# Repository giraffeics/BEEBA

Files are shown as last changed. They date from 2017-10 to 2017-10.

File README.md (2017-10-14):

# BEEBA

An 8-bit computer built using 7400 Series discrete logic chips.

## Repository Layout

The "CAD" folder contains all design files for the printed circuit boards. These are KiCAD documents.
The "Assembler" folder contains the C++ source code for the assembler, as well as the list of register names and some programs written in BEEBA assembly language. The assembler can be compiled with MinGW on Windows, and has not been tested on other compilers or operating systems.

## Assembly Language

Assembly language programs can be in any plain-text file format. The language is not case-sensitive. Each instruction copies eight bits of data from one register location to another. A line of code can follow one of three formats:

### COPY [read location] TO [write location]

Reads one byte of data from the register specified by [read location], writes data to the register specified by [write location].

### SET [write location] TO [data]

Writes a byte of data specified by [data] to the register specified by [write location]. [data] can be a two-digit hexadecimal number or a marker.

### MARK [marker name]

Marks the instruction position that corresponds to the following line of code. This does not represent an actual instruction. [marker name] can be referenced by SET instructions before or after the location of the marker, using a colon to specify which byte of the marker's location to use. This ranges from 0 (least significant) to 2 (most significant).

For all of these, any text after the last parameter will be ignored. However, it must be separated by a space or tab from the last parameter.

Register names are listed in REGISTER_NAMES.txt. The assembler uses this file to convert names to addresses while compiling programs.

## Using The Assembler

To use the assembler, simply drag assembly source files onto the compiled executable.

As BEEBA uses two physical ROM chips to store 16-bit-wide instructions, the assembler will output two .bin files. One of these is loaded onto the ROM chip on the left, the other is loaded onto the ROM chip on the right. They are named accordingly.

## Known Issues

When writing a constant to a register, the value will be corrupted unless the same data is sent to another register in the next instruction. The current workaround is to send data to NULL, which is an unused register.

The NES controller interface board cannot read the state of the A button. Pannenkoek2012 would love this.

The "Basic IO Board"'s input does not work at all. This was caused by oversights during the transition from TTL to CMOS. Output is still fully functional.

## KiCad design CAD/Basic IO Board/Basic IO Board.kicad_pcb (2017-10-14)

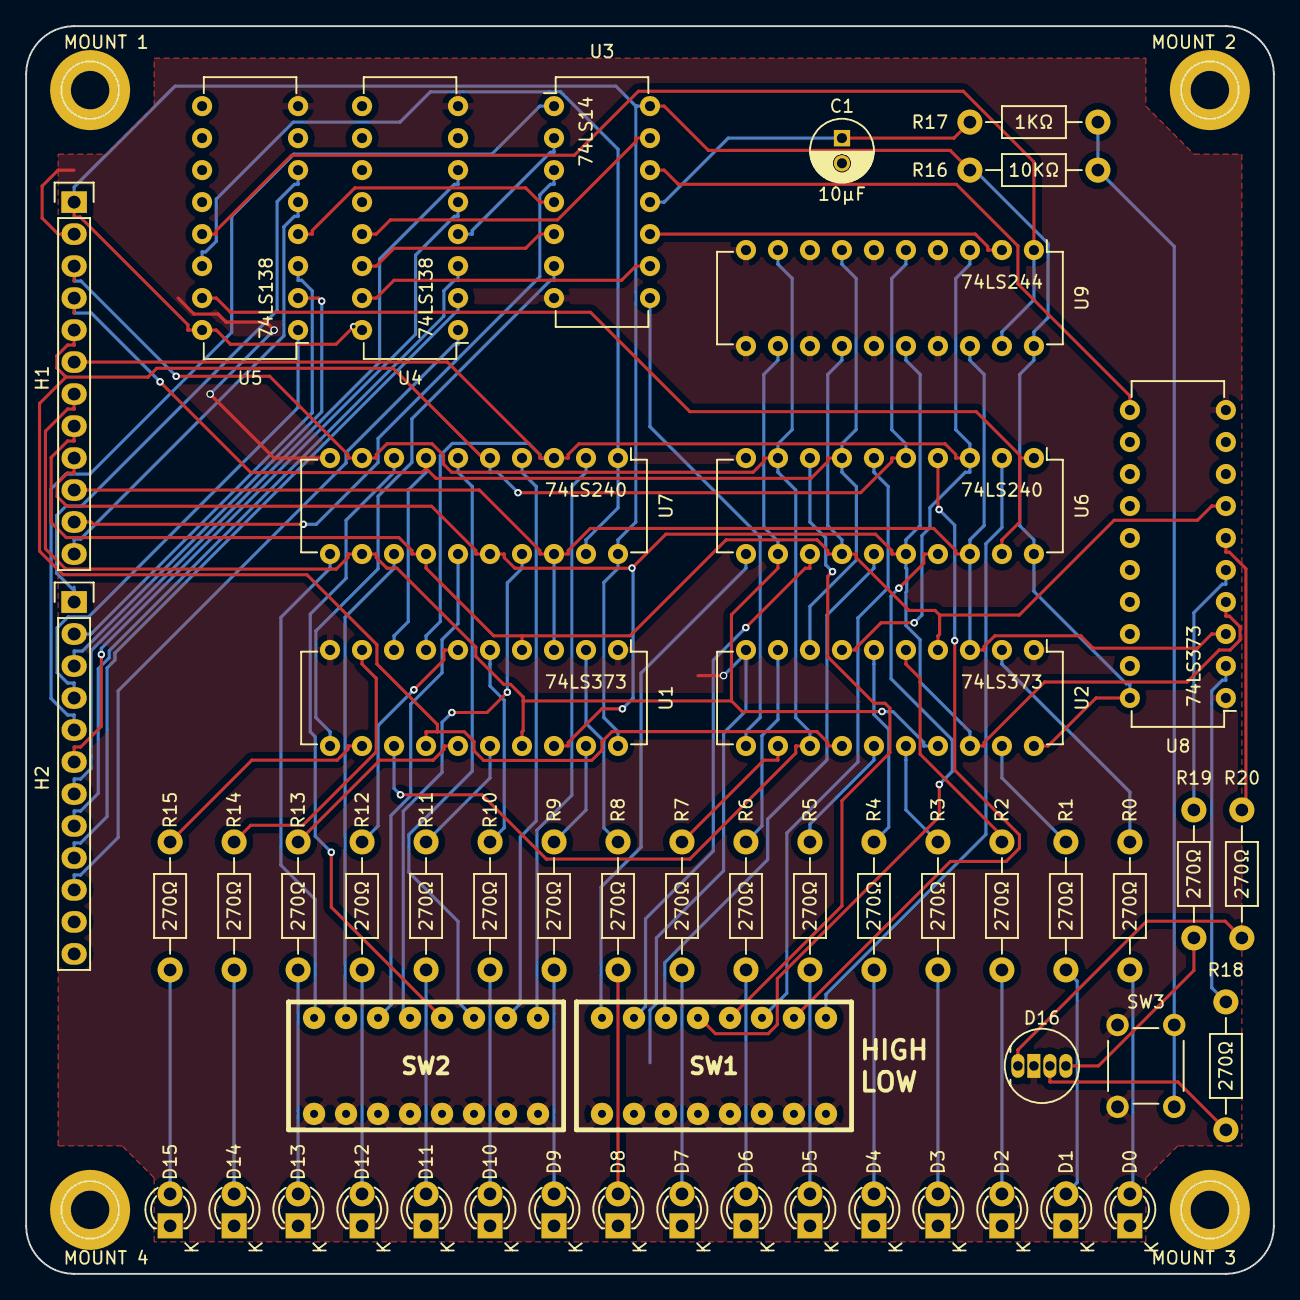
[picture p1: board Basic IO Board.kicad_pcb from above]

Board: 2 copper layers, 99.1 x 99.1 mm, 57 parts (0 on the bottom side), 90 nets.

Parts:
C1: 10µF; C_Radial_D5_L11_P2
D0, D1, D2, D3, D4, D5, D6, D7, D8, D9, D10, D11, D12, D13, D14, D15: Led_Small; LED-3MM
D16: LED_RCBG; LED-RGB-5MM_Common_Cathode
H1, H2: CONN_01X12; Socket_Strip_Straight_1x12
MOUNT 1, MOUNT 2, MOUNT 3, MOUNT 4: 1pin
R0, R1, R2, R3, R4, R5, R6, R7, R8, R9, R10, R11, R12, R13, R14, R15, R18, R19, R20: 270Ω; Resistor_Horizontal_RM10mm
R16: 10KΩ; Resistor_Horizontal_RM10mm
R17: 1KΩ; Resistor_Horizontal_RM10mm
SW1, SW2: DIPS_08; DIPS-DS08
SW3: SW_PUSH; switch_tactile_6mm
U1, U2, U8: 74LS373; DIP-20_W7.62mm
U3: 74LS14; DIP-14_W7.62mm
U4, U5: 74LS138; DIP-16_W7.62mm
U6, U7: 74LS240; DIP-20_W7.62mm
U9: 74LS244; DIP-20_W7.62mm

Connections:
DATA0: H1.10, U1.3, U2.3, U6.18, U7.18, U8.3, U9.18
DATA1: H1.9, U1.18, U2.18, U6.16, U7.16, U8.4, U9.16
DATA2: H1.8, U1.4, U2.4, U6.14, U7.14, U8.7, U9.14
DATA3: H1.7, U1.17, U2.17, U6.12, U7.12, U9.12
DATA4: H1.6, U1.7, U2.7, U6.3, U7.3, U9.3
DATA5: H1.5, U1.14, U2.14, U6.5, U7.5, U9.5
DATA6: H1.4, U1.8, U2.8, U6.7, U7.7, U9.7
DATA7: H1.3, U1.13, U2.13, U6.9, U7.9, U9.9
GND: C1.2, D0.1, D1.1, D2.1, D3.1, D4.1, D5.1, D6.1, D7.1, D8.1, D9.1, D10.1, D11.1, D12.1, D13.1, D14.1, D15.1, D16.2, H1.2, SW1.9, SW1.10, SW1.11, SW1.12, SW1.13, SW1.14, SW1.15, SW1.16, SW2.9, SW2.10, SW2.11, SW2.12, SW2.13, SW2.14, SW2.15, SW2.16, SW3.1, U1.1, U1.10, U2.1, U2.10, U3.7, U4.8, U5.8, U6.10, U7.10, U8.1, U8.10, U9.4, U9.6, U9.8, U9.10, U9.11, U9.13, U9.15, U9.17
unnamed: C1.1, R17.1, U3.11
unnamed: D0.2, R0.2
unnamed: D1.2, R1.2
unnamed: D2.2, R2.2
unnamed: D3.2, R3.2
unnamed: D4.2, R4.2
unnamed: D5.2, R5.2
unnamed: D6.2, R6.2
unnamed: D7.2, R7.2
unnamed: D8.2, R8.2
unnamed: D9.2, R9.2
unnamed: D10.2, R10.2
unnamed: D11.2, R11.2
unnamed: D12.2, R12.2
unnamed: D13.2, R13.2
unnamed: D14.2, R14.2
unnamed: D15.2, R15.2
unnamed: D16.1, R20.1
unnamed: D16.3, R18.1
unnamed: D16.4, R19.1
unnamed: R0.1, U2.2
unnamed: R1.1, U2.19
unnamed: R2.1, U2.5
unnamed: R3.1, U2.16
unnamed: R4.1, U2.6
unnamed: R5.1, U2.15
unnamed: R6.1, U2.9
unnamed: R7.1, U2.12
unnamed: R8.1, U1.2
unnamed: R9.1, U1.19
unnamed: R10.1, U1.5
unnamed: R11.1, U1.16
unnamed: R12.1, U1.6
unnamed: R13.1, U1.15
unnamed: R14.1, U1.9
unnamed: R15.1, U1.12
unnamed: R16.2, R17.2, SW3.2
unnamed: R18.2, U8.2
unnamed: R19.2, U8.5
unnamed: R20.2, U8.6
unnamed: SW1.1, U6.2
unnamed: SW1.2, U6.4
unnamed: SW1.3, U6.6
unnamed: SW1.4, U6.8
unnamed: SW1.5, U6.17
unnamed: SW1.6, U6.15
unnamed: SW1.7, U6.13
unnamed: SW1.8, U6.11
unnamed: SW2.1, U7.2
unnamed: SW2.2, U7.4
unnamed: SW2.3, U7.6
unnamed: SW2.4, U7.8
unnamed: SW2.5, U7.17
unnamed: SW2.6, U7.15
unnamed: SW2.7, U7.13
unnamed: SW2.8, U7.11
unnamed: U1.11, U3.6
unnamed: U2.11, U3.8
unnamed: U3.2, U4.4
unnamed: U3.4, U5.4
unnamed: U3.10, U9.2
unnamed: U3.12, U8.11
READ0: H2.4, U5.1
READ1: H2.3, U5.2
READ2: H2.2, U5.3
READ3: H2.1, U5.6
READ4: H1.12, U5.5
READ5: H1.11, U3.3
RS40: U5.15, U6.1, U6.19
RS41: U5.14, U7.1, U7.19
RS42: U5.13, U9.1, U9.19
VCC: H1.1, R16.1, U1.20, U2.20, U3.14, U4.16, U5.16, U6.20, U7.20, U8.20, U9.20
WRITE0: H2.10, U4.1
WRITE1: H2.9, U4.2
WRITE2: H2.8, U4.3
WRITE3: H2.7, U4.6
WRITE4: H2.6, U4.5
WRITE5: H2.5, U3.1
WS40: U3.9, U4.15
WS41: U3.5, U4.14
WS42: U3.13, U4.13

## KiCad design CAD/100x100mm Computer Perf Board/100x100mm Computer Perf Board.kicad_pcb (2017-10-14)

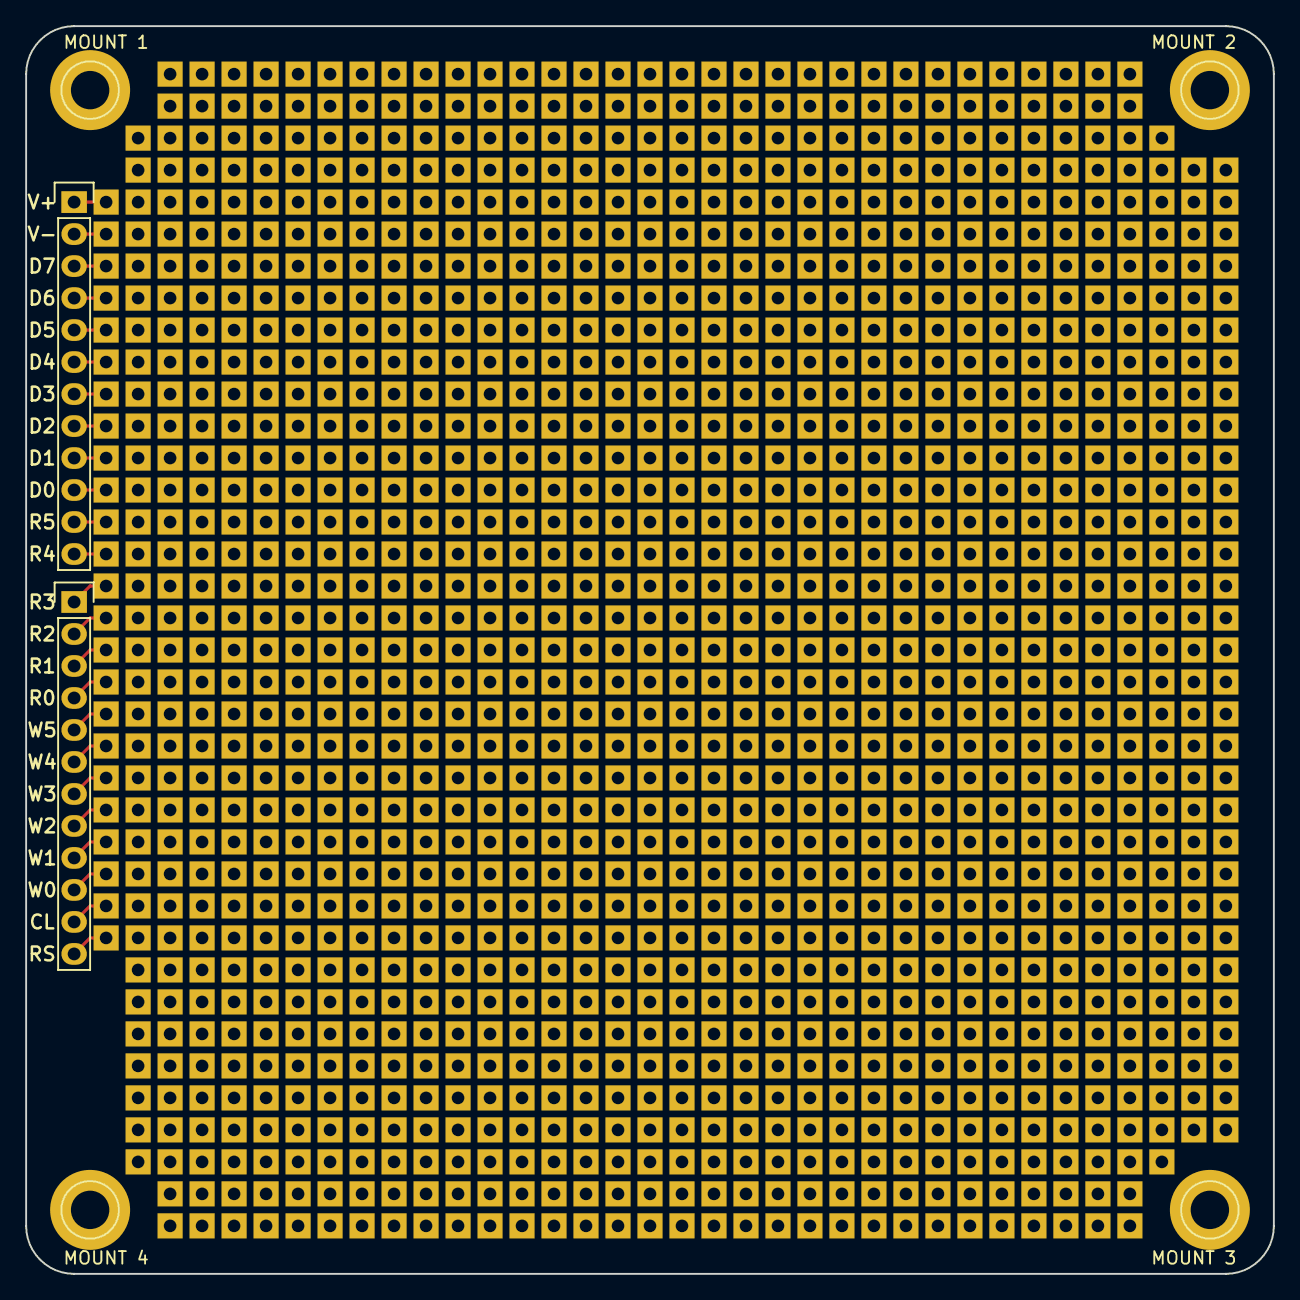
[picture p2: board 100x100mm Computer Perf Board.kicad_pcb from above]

Board: 2 copper layers, 99.1 x 99.1 mm, 1283 parts (0 on the bottom side), 24 nets.

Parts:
111, 112, 113, 114, 115, 116, 117, 118, 119, 121, 122, 123, 124, 125, 126, 127, 128, 129, 131, 132, 133, 134, 135, 136, 137, 138, 139, 141, 142, 143, 144, 145, 146, 147, 148, 149, 151, 152, 153, 154, 155, 156, 157, 158, 159, 161, 162, 163, 164, 165, 166, 167, 168, 169, 171, 172, 173, 174, 175, 176, 177, 178, 179, 181, 182, 183, 184, 185, 186, 187, 188, 189, 191, 192, 193, 194, 195, 196, 197, 198, 199, 1101, 1102, 1103, 1104, 1105, 1106, 1107, 1108, 1109, 1110, 1111, 1111#2, 1111#3, 1112, 1112#2, 1112#3, 1113, 1113#2, 1113#3, 1114, 1114#2, 1114#3, 1115, 1115#2, 1115#3, 1116, 1116#2, 1116#3, 1117, 1117#2, 1117#3, 1118, 1118#2, 1118#3, 1119, 1119#2, 1119#3, 1120, 1121, 1121#2, 1122, 1122#2, 1123, 1123#2, 1124, 1124#2, 1125, 1125#2, 1126, 1126#2, 1127, 1127#2, 1128, 1128#2, 1129, 1129#2, 1130, 1131, 1131#2, 1132, 1132#2, 1133, 1133#2, 1134, 1134#2, 1135, 1135#2, 1136, 1136#2, 1137, 1137#2, 1138, 1139, 1141, 1142, 1143, 1144, 1145, 1146, 1147, 1148, 1149, 1151, 1152, 1153, 1154, 1155, 1156, 1157, 1158, 1159, 1161, 1162, 1163, 1164, 1165, 1166, 1167, 1168, 1169, 1171, 1172, 1173, 1174, 1175, 1176, 1177, 1178, 1179, 1181, 1182, 1183, 1184, 1185, 1186, 1187, 1188, 1189, 1191, 1192, 1193, 1194, 1195, 1196, 1197, 1198, 1199, 1201, 1202, 1203, 1204, 1205, 1206, 1207, 1208, 1209, 1210, 1211, 1211#2, 1212, 1212#2, 1213, 1213#2, 1214, 1214#2, 1215, 1215#2, 1216, 1216#2, 1217, 1217#2, 1218, 1218#2, 1219, 1219#2, 1220, 1221, 1221#2, 1222, 1222#2, 1223, 1223#2, 1224, 1224#2, 1225, 1225#2, 1226, 1226#2, 1227, 1227#2, 1228, 1228#2, 1229, 1229#2, 1230, 1231, 1231#2, 1232, 1232#2, 1233, 1233#2, 1234, 1234#2, 1235, 1235#2, 1236, 1236#2, 1237, 1237#2, 1238, 1239, 1241, 1242, 1243, 1244, 1245, 1246, 1247, 1248, 1249, 1251, 1252, 1253, 1254, 1255, 1256, 1257, 1258, 1259, 1261, 1262, 1263, 1264, 1265, 1266, 1267, 1268, 1269, 1271, 1272, 1273, 1274, 1275, 1276, 1277, 1278, 1279, 1281, 1282, 1283, 1284, 1285, 1286, 1287, 1288, 1289, 1291, 1292, 1293, 1294, 1295, 1296, 1297, 1298, 1299, 1301, 1302, 1303, 1304, 1305, 1306, 1307, 1308, 1309, 1310, 1311, 1311#2, 1312, 1312#2, 1313, 1313#2, 1314, 1314#2, 1315, 1315#2, 1316, 1316#2, 1317, 1317#2, 1318, 1318#2, 1319, 1319#2, 1320, 1321, 1322, 1323, 1324, 1325, 1326, 1327, 1328, 1329, 1330, 1331, 1332, 1333, 1334, 1335, 1336, 1337, 1410, 1411, 1412, 1413, 1414, 1415, 1416, 1417, 1418, 1419, 1420, 1421, 1422, 1423, 1424, 1425, 1426, 1427, 1428, 1429, 1430, 1431, 1432, 1433, 1434, 1435, 1436, 1437, 1510, 1511, 1512, 1513, 1514, 1515, 1516, 1517, 1518, 1519, 1520, 1521, 1522, 1523, 1524, 1525, 1526, 1527, 1528, 1529, 1530, 1531, 1532, 1533, 1534, 1535, 1536, 1537, 1610, 1611, 1612, 1613, 1614, 1615, 1616, 1617, 1618, 1619, 1620, 1621, 1622, 1623, 1624, 1625, 1626, 1627, 1628, 1629, 1630, 1631, 1632, 1633, 1634, 1635, 1636, 1637, 1710, 1711, 1712, 1713, 1714, 1715, 1716, 1717, 1718, 1719, 1720, 1721, 1722, 1723, 1724, 1725, 1726, 1727, 1728, 1729, 1730, 1731, 1732, 1733, 1734, 1735, 1736, 1737, 1810, 1811, 1812, 1813, 1814, 1815, 1816, 1817, 1818, 1819, 1820, 1821, 1822, 1823, 1824, 1825, 1826, 1827, 1828, 1829, 1830, 1831, 1832, 1833, 1834, 1835, 1836, 1837, 1910, 1911, 1912, 1913, 1914, 1915, 1916, 1917, 1918, 1919, 1920, 1921, 1922, 1923, 1924, 1925, 1926, 1927, 1928, 1929, 1930, 1931, 1932, 1933, 1934, 1935, 1936, 1937, 11010, 11011, 11012, 11013, 11014, 11015, 11016, 11017, 11018, 11019, 11020, 11021, 11022, 11023, 11024, 11025, 11026, 11027, 11028, 11029, 11030, 11031, 11032, 11033, 11034, 11035, 11036, 11037, 11110, 11110#2, 11111, 11111#2, 11112, 11112#2, 11113, 11113#2, 11114, 11114#2, 11115, 11115#2, 11116, 11116#2, 11117, 11117#2, 11118, 11118#2, 11119, 11119#2, 11120, 11120#2, 11121, 11121#2, 11122, 11122#2, 11123, 11123#2, 11124, 11124#2, 11125, 11125#2, 11126, 11126#2, 11127, 11127#2, 11128, 11128#2, 11129, 11129#2, 11130, 11130#2, 11131, 11131#2, 11132, 11132#2, 11133, 11133#2, 11134, 11135, 11136, 11137, 11210, 11211, 11212, 11213, 11214, 11215, 11216, 11217, 11218, 11219, 11220, 11221, 11222, 11223, 11224, 11225, 11226, 11227, 11228, 11229, 11230, 11231, 11232, 11233, 11234, 11235, 11236, 11237, 11310, 11311, 11312, 11313, 11314, 11315, 11316, 11317, 11318, 11319, 11320, 11321, 11322, 11323, 11324, 11325, 11326, 11327, 11328, 11329, 11330, 11331, 11332, 11333, 11334, 11335, 11336, 11337, 11410, 11411, 11412, 11413, 11414, 11415, 11416, 11417, 11418, 11419, 11420, 11421, 11422, 11423, 11424, 11425, 11426, 11427, 11428, 11429, 11430, 11431, 11432, 11433, 11434, 11435, 11436, 11437, 11510, 11511, 11512, 11513, 11514, 11515, 11516, 11517, 11518, 11519, 11520, 11521, 11522, 11523, 11524, 11525, 11526, 11527, 11528, 11529, 11530, 11531, 11532, 11533, 11534, 11535, 11536, 11537, 11610, 11611, 11612, 11613, 11614, 11615, 11616, 11617, 11618, 11619, 11620, 11621, 11622, 11623, 11624, 11625, 11626, 11627, 11628, 11629, 11630, 11631, 11632, 11633, 11634, 11635, 11636, 11637, 11710, 11711, 11712, 11713, 11714, 11715, 11716, 11717, 11718, 11719, 11720, 11721, 11722, 11723, 11724, 11725, 11726, 11727, 11728, 11729, 11730, 11731, 11732, 11733, 11734, 11735, 11736, 11737, 11810, 11811, 11812, 11813, 11814, 11815, 11816, 11817, 11818, 11819, 11820, 11821, 11822, 11823, 11824, 11825, 11826, 11827, 11828, 11829, 11830, 11831, 11832, 11833, 11834, 11835, 11836, 11837, 11910, 11911, 11912, 11913, 11914, 11915, 11916, 11917, 11918, 11919, 11920, 11921, 11922, 11923, 11924, 11925, 11926, 11927, 11928, 11929, 11930, 11931, 11932, 11933, 11934, 11935, 11936, 11937, 12010, 12011, 12012, 12013, 12014, 12015, 12016, 12017, 12018, 12019, 12020, 12021, 12022, 12023, 12024, 12025, 12026, 12027, 12028, 12029, 12030, 12031, 12032, 12033, 12034, 12035, 12036, 12037, 12110, 12111, 12112, 12113, 12114, 12115, 12116, 12117, 12118, 12119, 12120, 12121, 12122, 12123, 12124, 12125, 12126, 12127, 12128, 12129, 12130, 12131, 12132, 12133, 12134, 12135, 12136, 12137, 12210, 12211, 12212, 12213, 12214, 12215, 12216, 12217, 12218, 12219, 12220, 12221, 12222, 12223, 12224, 12225, 12226, 12227, 12228, 12229, 12230, 12231, 12232, 12233, 12234, 12235, 12236, 12237, 12310, 12311, 12312, 12313, 12314, 12315, 12316, 12317, 12318, 12319, 12320, 12321, 12322, 12323, 12324, 12325, 12326, 12327, 12328, 12329, 12330, 12331, 12332, 12333, 12334, 12335, 12336, 12337, 12410, 12411, 12412, 12413, 12414, 12415, 12416, 12417, 12418, 12419, 12420, 12421, 12422, 12423, 12424, 12425, 12426, 12427, 12428, 12429, 12430, 12431, 12432, 12433, 12434, 12435, 12436, 12437, 12510, 12511, 12512, 12513, 12514, 12515, 12516, 12517, 12518, 12519, 12520, 12521, 12522, 12523, 12524, 12525, 12526, 12527, 12528, 12529, 12530, 12531, 12532, 12533, 12534, 12535, 12536, 12537, 12610, 12611, 12612, 12613, 12614, 12615, 12616, 12617, 12618, 12619, 12620, 12621, 12622, 12623, 12624, 12625, 12626, 12627, 12628, 12629, 12630, 12631, 12632, 12633, 12634, 12635, 12636, 12637, 12710, 12711, 12712, 12713, 12714, 12715, 12716, 12717, 12718, 12719, 12720, 12721, 12722, 12723, 12724, 12725, 12726, 12727, 12728, 12729, 12730, 12731, 12732, 12733, 12734, 12735, 12736, 12737, 12810, 12811, 12812, 12813, 12814, 12815, 12816, 12817, 12818, 12819, 12820, 12821, 12822, 12823, 12824, 12825, 12826, 12827, 12828, 12829, 12830, 12831, 12832, 12833, 12834, 12835, 12836, 12837, 12910, 12911, 12912, 12913, 12914, 12915, 12916, 12917, 12918, 12919, 12920, 12921, 12922, 12923, 12924, 12925, 12926, 12927, 12928, 12929, 12930, 12931, 12932, 12933, 12934, 12935, 12936, 12937, 13010, 13011, 13012, 13013, 13014, 13015, 13016, 13017, 13018, 13019, 13020, 13021, 13022, 13023, 13024, 13025, 13026, 13027, 13028, 13029, 13030, 13031, 13032, 13033, 13034, 13035, 13036, 13037, 13110, 13111, 13111#2, 13112, 13112#2, 13113, 13113#2, 13114, 13114#2, 13115, 13115#2, 13116, 13116#2, 13117, 13117#2, 13118, 13118#2, 13119, 13119#2, 13120, 13121, 13122, 13123, 13124, 13125, 13126, 13127, 13128, 13129, 13130, 13131, 13132, 13133, 13134, 13135, 13136, 13137, 131110, 131111, 131111#2, 131112, 131112#2, 131113, 131113#2, 131114, 131114#2, 131115, 131115#2, 131116, 131116#2, 131117, 131117#2, 131118, 131118#2, 131119, 131119#2, 131120, 131121, 131121#2, 131122, 131122#2, 131123, 131123#2, 131124, 131124#2, 131125, 131125#2, 131126, 131126#2, 131127, 131127#2, 131128, 131128#2, 131129, 131129#2, 131130, 131131, 131132, 131133, 1311110, 1311111, 1311112, 1311113, 1311114, 1311115, 1311116, 1311117, 1311118, 1311119, 1311120, 1311121, 1311122, 1311123, 1311124, 1311125, 1311126, 1311127, 1311128, 1311129, 1311130, 1311131, 1311210, 1311211, 1311212, 1311213, 1311214, 1311215, 1311216, 1311217, 1311218, 1311219, 1311220, 1311221, 1311222, 1311223, 1311224, 1311225, 1311226, 1311227, 1311228, 1311229, 1311230, 1311231: 1pin
H1, H2: CONN_01X12; Socket_Strip_Straight_1x12
H3, H4: CONN_01X12; 12pin_square_nodecor
MOUNT 1, MOUNT 2, MOUNT 3, MOUNT 4: 1pin

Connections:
DATA0: H1.10, H3.10
DATA1: H1.9, H3.9
DATA2: H1.8, H3.8
DATA3: H1.7, H3.7
DATA4: H1.6, H3.6
DATA5: H1.5, H3.5
DATA6: H1.4, H3.4
DATA7: H1.3, H3.3
GND: H1.2, H3.2
unnamed: H2.11, H4.11
unnamed: H2.12, H4.12
READ0: H2.4, H4.4
READ1: H2.3, H4.3
READ2: H2.2, H4.2
READ3: H2.1, H4.1
READ4: H1.12, H3.12
READ5: H1.11, H3.11
VCC: H1.1, H3.1
WRITE0: H2.10, H4.10
WRITE1: H2.9, H4.9
WRITE2: H2.8, H4.8
WRITE3: H2.7, H4.7
WRITE4: H2.6, H4.6
WRITE5: H2.5, H4.5

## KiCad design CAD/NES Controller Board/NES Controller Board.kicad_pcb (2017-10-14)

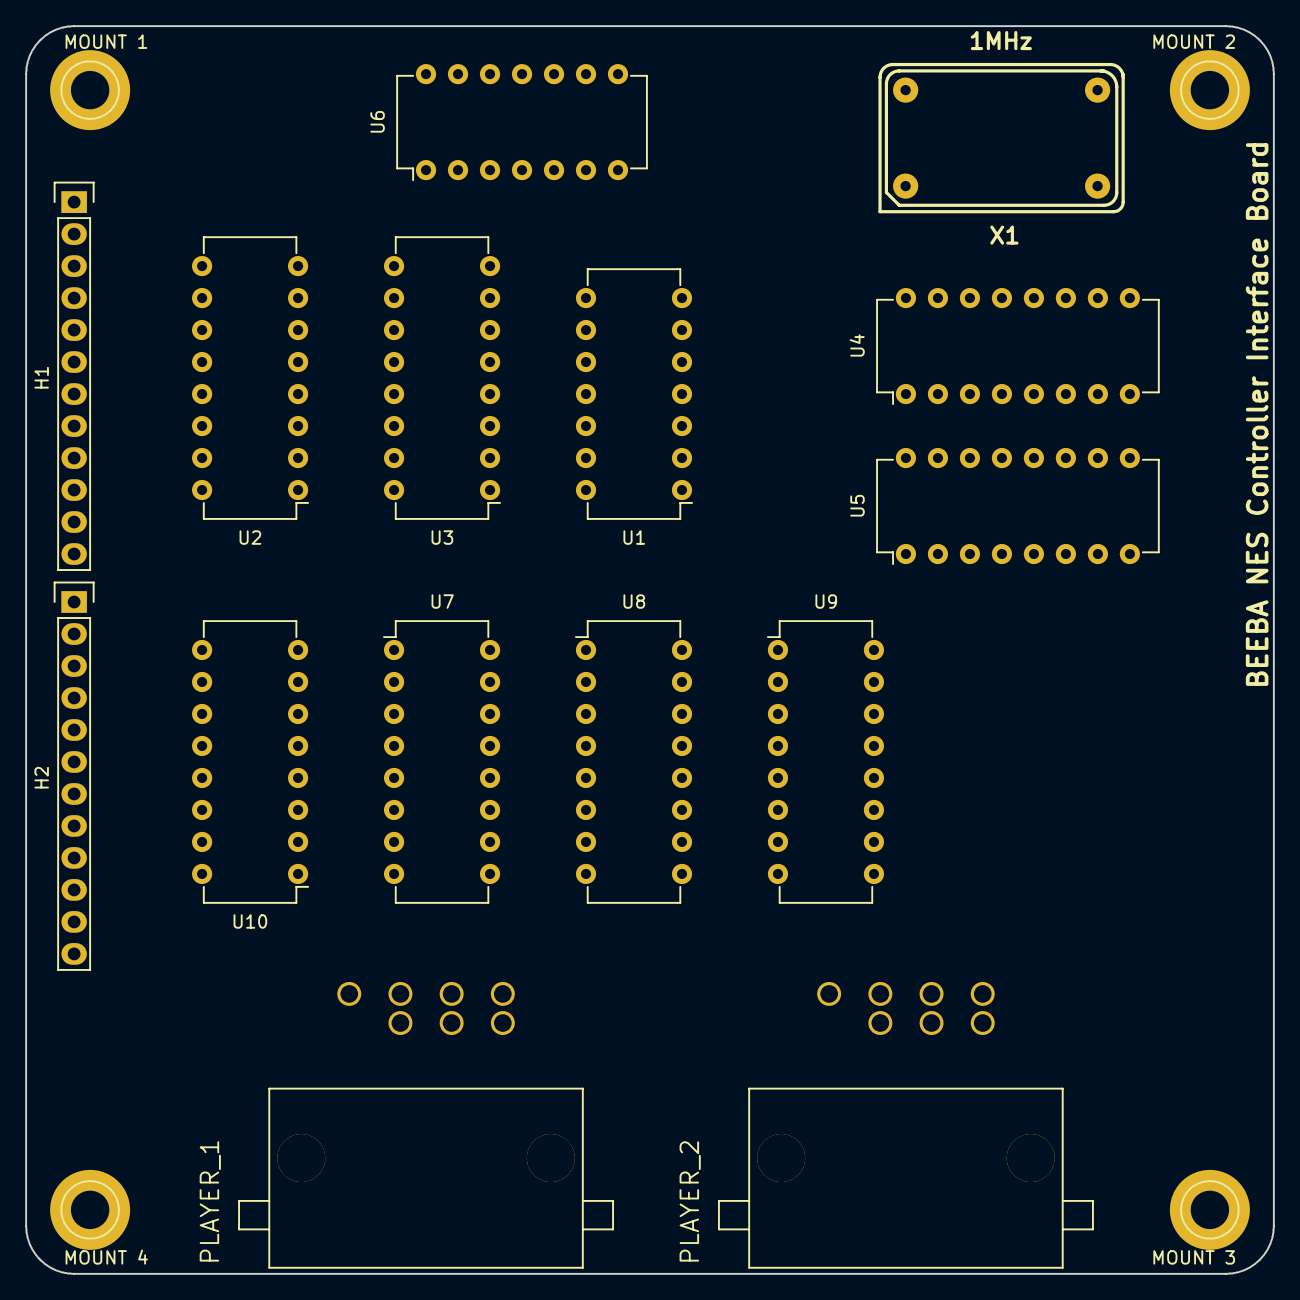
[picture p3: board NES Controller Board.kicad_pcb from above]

Board: 2 copper layers, 99.1 x 99.1 mm, 19 parts (0 on the bottom side), 42 nets, no tracks yet.

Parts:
H1, H2: CONN_01X12; Socket_Strip_Straight_1x12
MOUNT 1, MOUNT 2, MOUNT 3, MOUNT 4: 1pin
PLAYER_1, PLAYER_2: NES_Controller_Port; NES_Controller_Port_RA
U1: 74LS04; DIP-14_W7.62mm
U2, U3: 74LS595; DIP-16_W7.62mm
U4, U7, U8: 74LS193; DIP-16_W7.62mm
U5, U9: 74LS85; DIP-16_W7.62mm
U6: 74LS08; DIP-14_W7.62mm
U10: 74LS138; DIP-16_W7.62mm
X1: 1MHz; XO-14S

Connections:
CNT0: U1.1, U6.2, U7.3, U9.10
CNT1: U1.5, U7.2, U9.12
CNT2: U7.6, U9.13
CNT4: U1.3, U6.9, U8.3, U9.15
DATA0: H1.10, U2.15, U3.15
DATA1: H1.9, U2.1, U3.1
DATA2: H1.8, U2.2, U3.2
DATA3: H1.7, U2.3, U3.3
DATA4: H1.6, U2.4, U3.4
DATA5: H1.5, U2.5, U3.5
DATA6: H1.4, U2.6, U3.6
DATA7: H1.3, U2.7, U3.7
GND: PLAYER_1.1, PLAYER_2.1, U1.7, U2.8, U3.8, U4.8, U5.2, U5.4, U5.8, U5.10, U5.15, U6.7, U7.8, U8.8, U9.2, U9.4, U9.8, U9.14, U10.8, X1.7
LATCH: PLAYER_1.3, PLAYER_2.3, U2.12, U3.12, U6.8
NCNT4: U1.4, U6.1, U6.5
unnamed: PLAYER_1.2, PLAYER_2.2, U6.6
unnamed: U1.2, U6.4
unnamed: U1.6, U6.10
unnamed: U1.8, U10.4
unnamed: U1.10, U2.14
unnamed: U1.12, U3.14
unnamed: U2.11, U3.11, U6.3
unnamed: U4.2, U5.14
unnamed: U4.3, U5.1
unnamed: U4.5, X1.8
unnamed: U4.6, U5.11
unnamed: U4.7, U5.9
unnamed: U4.14, U5.6, U7.5
unnamed: U7.12, U8.5
unnamed: U7.13, U8.4
unnamed: U7.14, U8.14, U9.6
P1_DATA: PLAYER_1.4, U1.11
P2_DATA: PLAYER_2.4, U1.13
READ0: H2.4, U10.1
READ1: H2.3, U10.2
READ2: H2.2, U10.3
READ3: H2.1, U1.9
READ4: H1.12, U10.5
READ5: H1.11, U10.6
RS43: U2.13, U10.12
RS44: U3.13, U10.11
VCC: H1.1, PLAYER_1.7, PLAYER_2.7, U1.14, U2.10, U2.16, U3.10, U3.16, U4.4, U4.11, U4.16, U5.3, U5.12, U5.13, U5.16, U6.14, U7.4, U7.11, U7.16, U8.11, U8.16, U9.1, U9.3, U9.9, U9.11, U9.16, U10.16, X1.14

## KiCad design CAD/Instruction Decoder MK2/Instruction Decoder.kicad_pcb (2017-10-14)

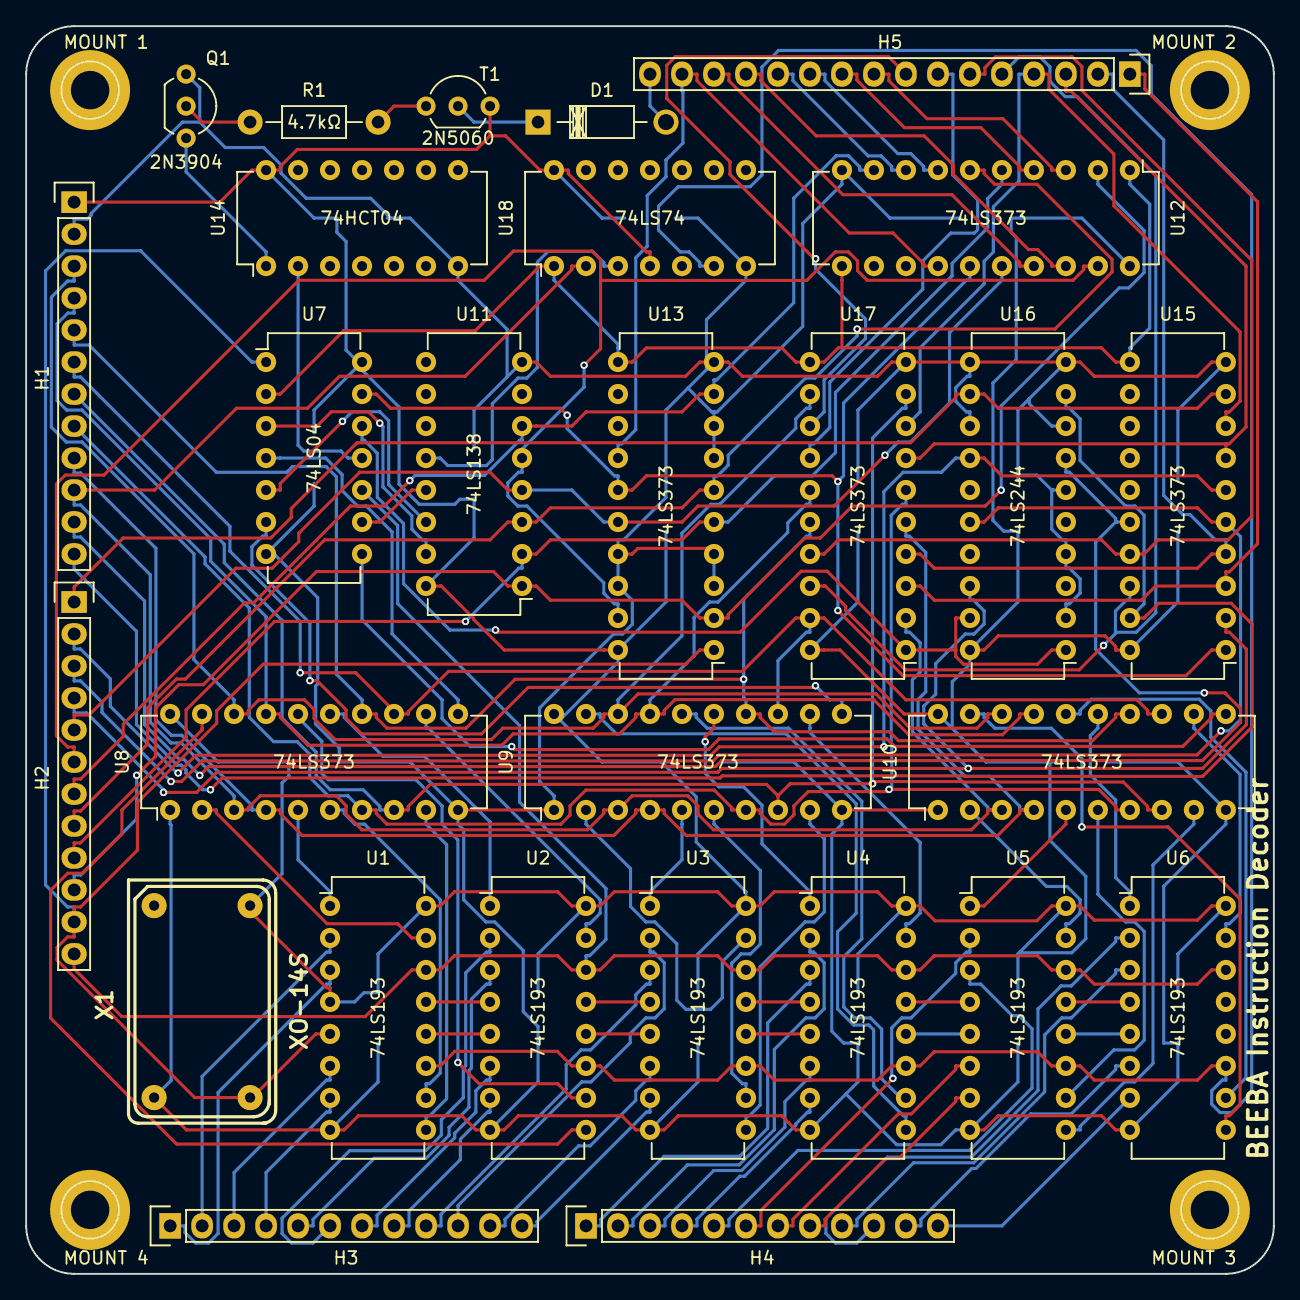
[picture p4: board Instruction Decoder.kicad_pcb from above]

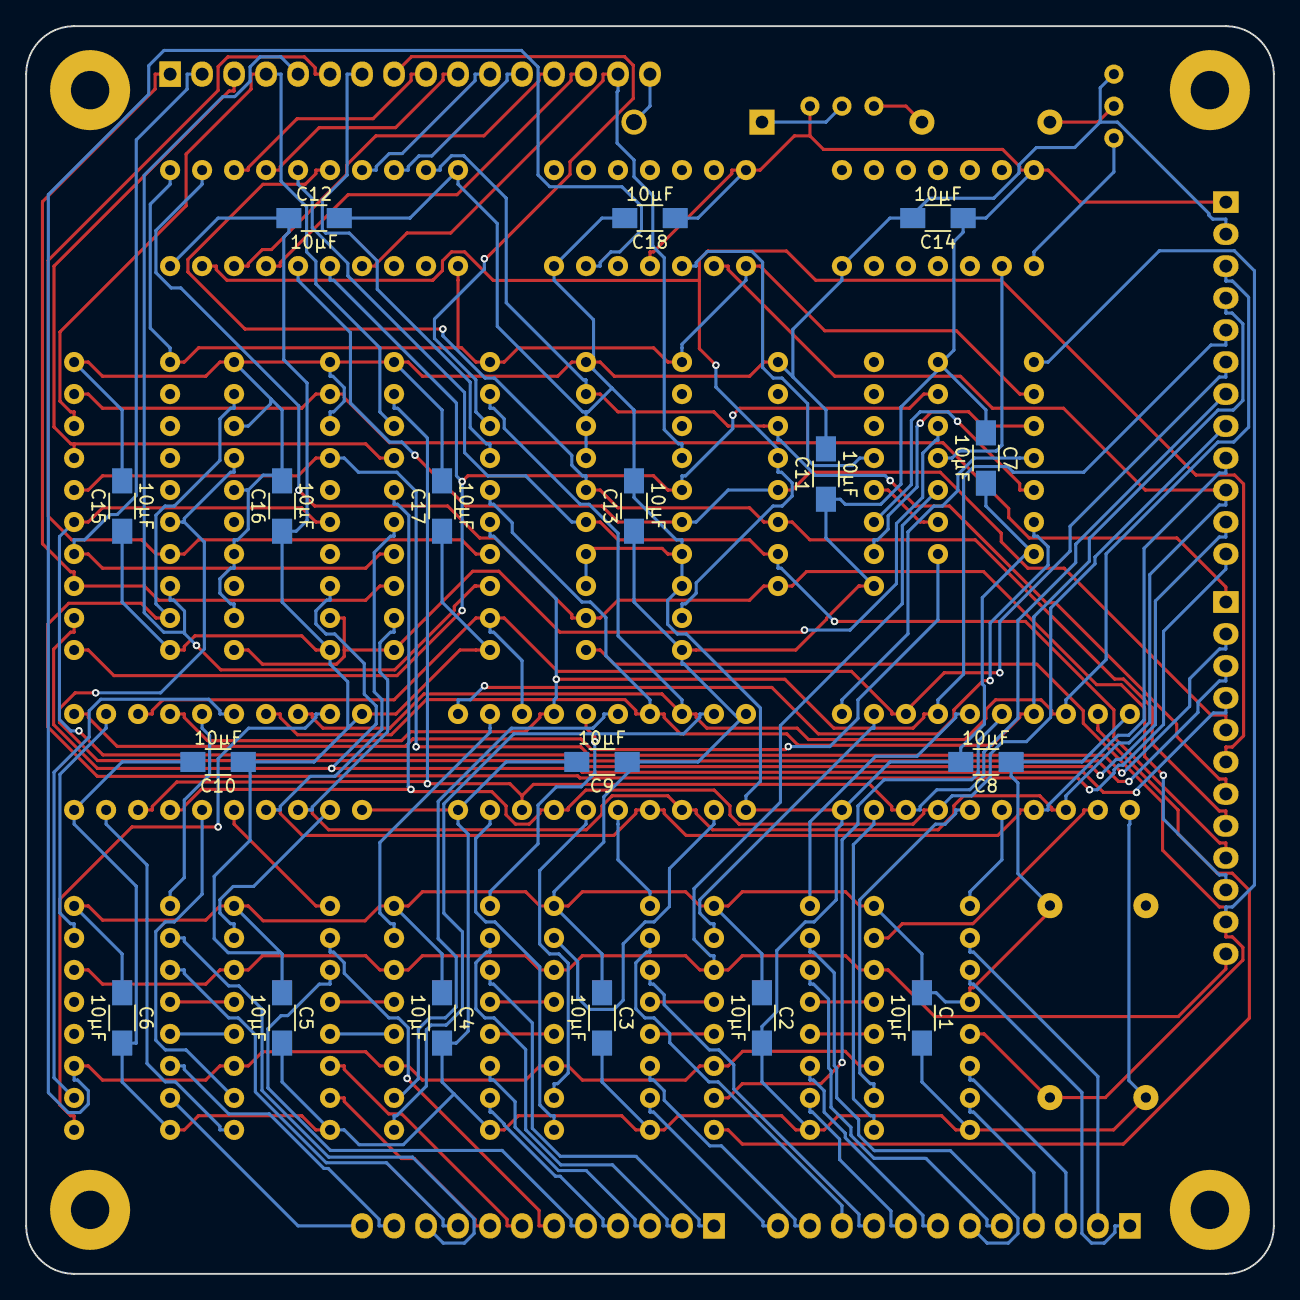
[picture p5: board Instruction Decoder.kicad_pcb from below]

Board: 2 copper layers, 99.1 x 99.1 mm, 50 parts (18 on the bottom side), 114 nets.

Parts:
C1, C2, C3, C4, C5, C6, C7, C8, C9, C10, C11, C12, C13, C14, C15, C16, C17, C18: 10µF; C_1206_HandSoldering
D1: D; Diode_DO-41_SOD81_Horizontal_RM10
H1, H2, H3, H4: CONN_01X12; Socket_Strip_Straight_1x12
H5: CONN_01X16; Socket_Strip_Straight_1x16
MOUNT 1, MOUNT 2, MOUNT 3, MOUNT 4: 1pin
Q1: 2N3904; TO-92_Inline_Wide
R1: 4.7kΩ; Resistor_Horizontal_RM10mm
T1: 2N5060; TO-92_Inline_Wide
U1, U2, U3, U4, U5, U6: 74LS193; DIP-16_W7.62mm
U7: 74LS04; DIP-14_W7.62mm
U8, U9, U10, U12, U13, U15, U17: 74LS373; DIP-20_W7.62mm
U11: 74LS138; DIP-16_W7.62mm
U14: 74HCT04; DIP-14_W7.62mm
U16: 74LS244; DIP-20_W7.62mm
U18: 74LS74; DIP-14_W7.62mm
X1: XO-14S

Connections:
CLOCK: H2.11, U1.5, U7.1, U13.1, X1.8
DATA0: H1.10, U8.3, U9.3, U10.3, U17.2, U18.2
DATA1: H1.9, U8.4, U9.4, U10.4, U17.5
DATA2: H1.8, U8.7, U9.7, U10.7, U17.6
DATA3: H1.7, U8.8, U9.8, U10.8, U17.9
DATA4: H1.6, U8.13, U9.13, U10.13, U17.19
DATA5: H1.5, U8.14, U9.14, U10.14, U17.16
DATA6: H1.4, U8.17, U9.17, U10.17, U17.15
DATA7: H1.3, U8.18, U9.18, U10.18, U17.12
GND: C1.2, C2.2, C3.2, C4.2, C5.2, C6.2, C7.2, C8.2, C9.2, C10.2, C11.2, C12.2, C13.2, C14.2, C15.2, C16.2, C17.2, C18.2, H1.2, Q1.1, U1.8, U2.8, U3.8, U4.8, U5.8, U6.8, U7.7, U8.1, U8.10, U9.1, U9.10, U10.1, U10.10, U11.8, U12.10, U13.3, U13.4, U13.7, U13.8, U13.10, U13.17, U13.18, U14.7, U15.10, U16.2, U16.4, U16.6, U16.8, U16.10, U16.11, U16.13, U17.10, U18.7, X1.7
II00: H5.1, U15.3, U17.3
II01: H5.2, U15.4, U17.4
II02: H5.3, U15.7, U17.7
II03: H5.4, U15.8, U17.8
II04: H5.5, U15.18, U17.18
II05: H5.6, U15.17, U17.17
II06: H5.7, U17.14
II07: H5.8, U17.13
II08: H5.9, U12.3
II09: H5.10, U12.4
II10: H5.11, U12.7
II11: H5.12, U12.8
II12: H5.13, U12.18
II13: H5.14, U12.17
II14: H5.15, U12.14, U13.14
II15: D1.2, H5.16
IL14: U7.13, U12.15, U13.15, U15.1
LOADP: U1.11, U2.11, U3.11, U4.11, U5.11, U6.11, U18.6
NCLOCK: U7.2, U12.1, U12.11, U13.11, U15.11, U17.11, U18.1
unnamed: D1.1, T1.G
unnamed: Q1.2, R1.2
unnamed: Q1.3, U14.1
unnamed: R1.1, T1.K
unnamed: U1.12, U2.5
unnamed: U1.13, U2.4
unnamed: U2.12, U3.5
unnamed: U2.13, U3.4
unnamed: U3.12, U4.5
unnamed: U3.13, U4.4
unnamed: U5.12, U6.5
unnamed: U5.13, U6.4
unnamed: U7.4, U8.11
unnamed: U7.6, U9.11
unnamed: U7.8, U10.11
unnamed: U7.11, U14.2
unnamed: U7.12, U16.1, U16.19, U17.1
PI00: U1.15, U8.2
PI01: U1.1, U8.5
PI02: U1.10, U8.6
PI03: U1.9, U8.9
PI04: U2.15, U8.12
PI05: U2.1, U8.15
PI06: U2.10, U8.16
PI07: U2.9, U8.19
PI08: U3.15, U9.2
PI09: U3.1, U9.5
PI10: U3.10, U9.6
PI11: U3.9, U9.9
PI12: U4.15, U9.12
PI13: U4.1, U9.15
PI14: U4.10, U9.16
PI15: U4.9, U9.19
PI16: U5.15, U10.2
PI17: U5.1, U10.5
PI18: U5.10, U10.6
PI19: U5.9, U10.9
PI20: U6.15, U10.12
PI21: U6.1, U10.15
PI22: U6.10, U10.16
PI23: U6.9, U10.19
PO00: H3.1, U1.3
PO01: H3.2, U1.2
PO02: H3.3, U1.6
PO03: H3.4, U1.7
PO04: H3.5, U2.3
PO05: H3.6, U2.2
PO06: H3.7, U2.6
PO07: H3.8, U2.7
PO08: H3.9, U3.3
PO09: H3.10, U3.2
PO10: H3.11, U3.6
PO11: H3.12, U3.7
PO12: H4.1, U4.3
PO13: H4.2, U4.2
PO14: H4.3, U4.6
PO15: H4.4, U4.7
PO16: H4.5, U5.3
PO17: H4.6, U5.2
PO18: H4.7, U5.6
PO19: H4.8, U5.7
PO20: H4.9, U6.3
PO21: H4.10, U6.2
PO22: H4.11, U6.6
PO23: H4.12, U6.7
READ0: H2.4, U15.2, U16.18
READ1: H2.3, U15.5, U16.16
READ2: H2.2, U15.6, U16.14
READ3: H2.1, U15.9, U16.12
READ4: H1.12, U15.19, U16.9
READ5: H1.11, U15.16, U16.7
RESET: H2.12, U1.14, U2.14, U3.14, U4.14, U5.14, U6.14, U7.10
TC1: U4.12, U5.5
TC2: U4.13, U5.4
VCC: C1.1, C2.1, C3.1, C4.1, C5.1, C6.1, C7.1, C8.1, C9.1, C10.1, C11.1, C12.1, C13.1, C14.1, C15.1, C16.1, C17.1, C18.1, H1.1, T1.A, U1.4, U1.16, U2.16, U3.16, U4.16, U5.16, U6.16, U7.14, U8.20, U9.20, U10.20, U11.16, U12.20, U13.20, U14.14, U15.20, U16.20, U17.20, U18.4, U18.14, X1.14
WRITE0: H2.10, U11.1, U12.2, U13.2
WRITE1: H2.9, U11.2, U12.5, U13.5
WRITE2: H2.8, U11.3, U12.6, U13.6
WRITE3: H2.7, U11.6, U12.9, U13.9
WRITE4: H2.6, U11.5, U12.19, U13.19
WRITE5: H2.5, U11.4, U12.16, U13.16
WS08: U7.3, U11.15
WS09: U7.5, U11.14
WS10: U7.9, U11.13
WS11: U11.12, U18.3

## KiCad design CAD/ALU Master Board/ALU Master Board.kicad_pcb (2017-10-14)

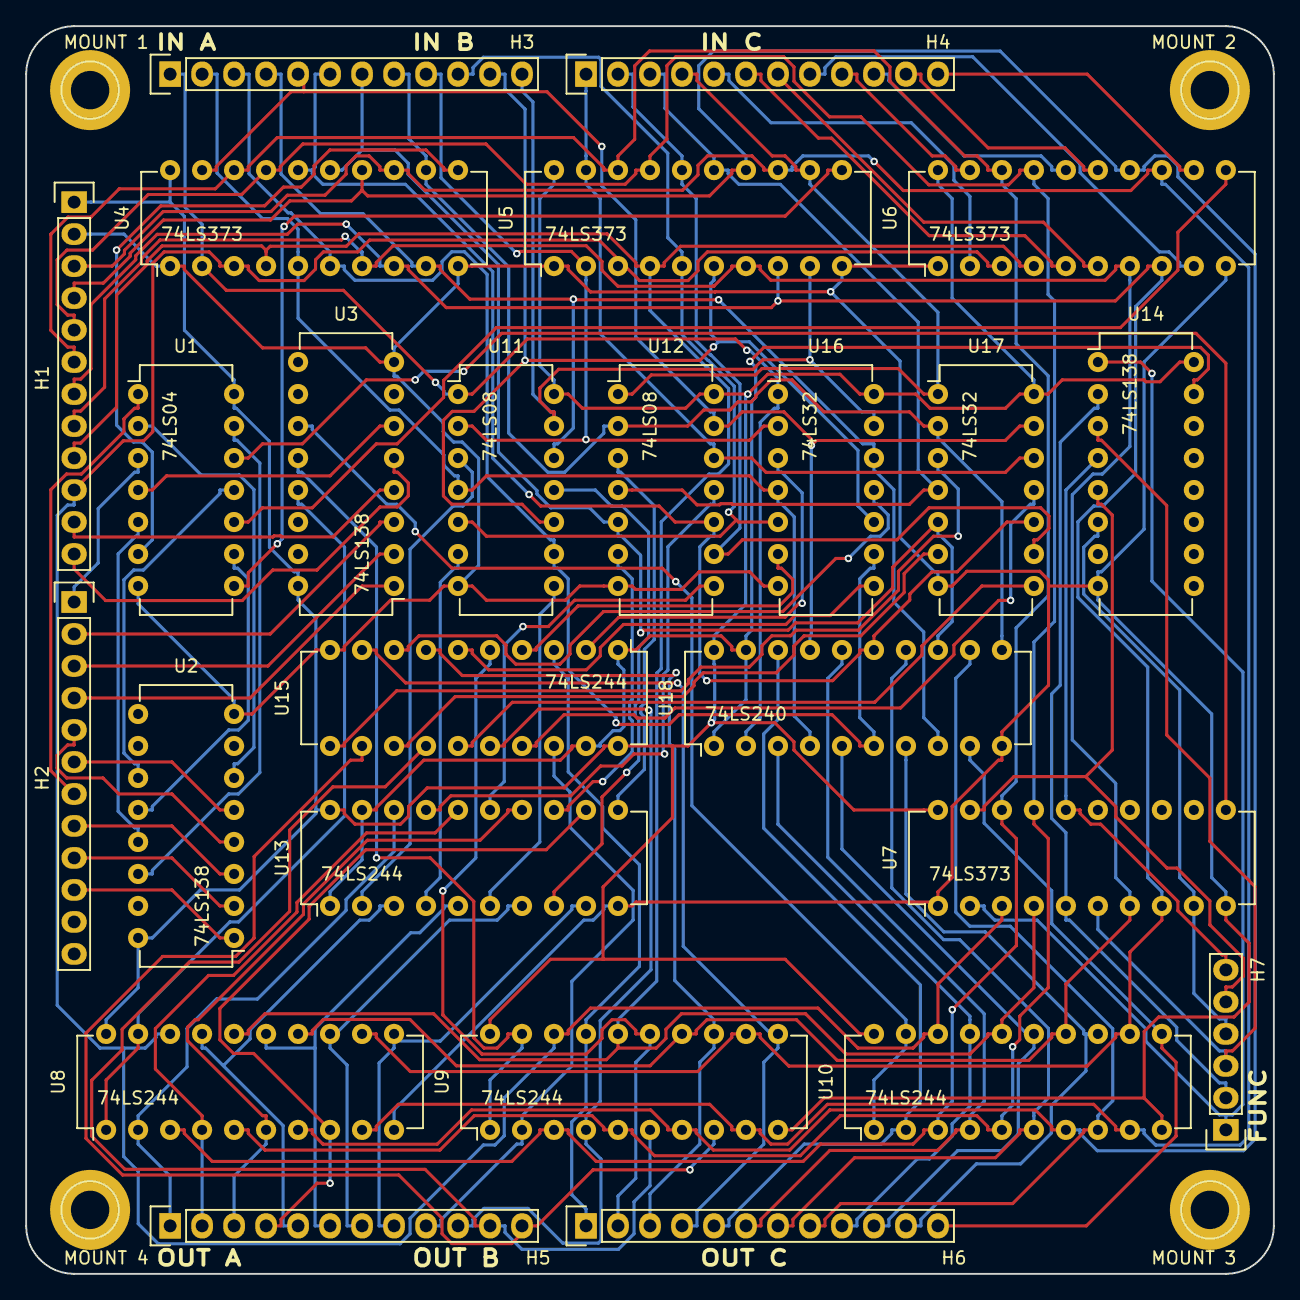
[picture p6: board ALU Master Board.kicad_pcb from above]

Board: 2 copper layers, 99.1 x 99.1 mm, 29 parts (0 on the bottom side), 106 nets.

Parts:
H1, H2, H3, H4, H5, H6: CONN_01X12; Socket_Strip_Straight_1x12
H7: CONN_01X06; Socket_Strip_Straight_1x06
MOUNT 1, MOUNT 2, MOUNT 3, MOUNT 4: 1pin
U1: 74LS04; DIP-14_W7.62mm
U2, U3, U14: 74LS138; DIP-16_W7.62mm
U4, U5, U6, U7: 74LS373; DIP-20_W7.62mm
U8, U9, U10, U13, U15: 74LS244; DIP-20_W7.62mm
U11, U12: 74LS08; DIP-14_W7.62mm
U16, U17: 74LS32; DIP-14_W7.62mm
U18: 74LS240; DIP-20_W7.62mm

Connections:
DATA0: H1.10, U4.3, U5.3, U6.3, U7.3, U8.18, U9.18, U10.18
DATA1: H1.9, U4.4, U5.4, U6.4, U7.4, U8.16, U9.16, U10.16
DATA2: H1.8, U4.7, U5.7, U6.7, U7.7, U8.14, U9.14, U10.14
DATA3: H1.7, U4.8, U5.8, U6.8, U7.8, U8.12, U9.12, U10.12
DATA4: H1.6, U4.18, U5.18, U6.18, U7.18, U8.3, U9.3, U10.3
DATA5: H1.5, U4.17, U5.17, U6.17, U7.17, U8.5, U9.5, U10.5
DATA6: H1.4, U4.14, U5.14, U6.14, U8.7, U9.7, U10.7
DATA7: H1.3, U4.13, U5.13, U6.13, U8.9, U9.9, U10.9
FS08: U13.1, U13.19, U14.15, U15.1, U15.19, U18.1, U18.19
FUNC0: H7.1, U7.2, U14.1
FUNC1: H7.2, U7.5, U14.2
FUNC2: H7.3, U7.6, U14.3
FUNC3: H7.4, U7.9, U14.6
FUNC4: H7.5, U7.19, U14.5
FUNC5: H7.6, U7.16, U14.4
GND: H1.2, U1.7, U2.8, U3.8, U4.1, U4.10, U5.1, U5.10, U6.1, U6.10, U7.1, U7.10, U8.10, U9.10, U10.10, U11.7, U12.7, U13.10, U14.8, U15.10, U16.7, U17.7, U18.10
INA0: H3.1, U4.2, U11.1, U16.1, U18.2
INA1: H3.2, U4.5, U11.4, U16.4, U18.4
INA2: H3.3, U4.6, U11.9, U16.9, U18.6
INA3: H3.4, U4.9, U11.12, U16.12, U18.8
INA4: H3.5, U4.19, U12.13, U17.13, U18.17
INA5: H3.6, U4.16, U12.10, U17.10, U18.15
INA6: H3.7, U4.15, U12.5, U17.5, U18.13
INA7: H3.8, U4.12, U12.2, U17.2, U18.11
INB0: H3.9, U5.2, U11.2, U16.2
INB1: H3.10, U5.5, U11.5, U16.5
INB2: H3.11, U5.6, U11.10, U16.10
INB3: H3.12, U5.9, U11.13, U16.13
INB4: H4.1, U5.19, U12.12, U17.12
INB5: H4.2, U5.16, U12.9, U17.9
INB6: H4.3, U5.15, U12.4, U17.4
INB7: H4.4, U5.12, U12.1, U17.1
INC0: H4.5, U6.2
INC1: H4.6, U6.5
INC2: H4.7, U6.6
INC3: H4.8, U6.9
INC4: H4.9, U6.19
INC5: H4.10, U6.16
INC6: H4.11, U6.15
INC7: H4.12, U6.12
unnamed: U1.2, U2.6
unnamed: U1.4, U3.6
unnamed: U1.6, U4.11
unnamed: U1.8, U5.11
unnamed: U1.10, U6.11
unnamed: U1.12, U7.11
unnamed: U11.3, U13.2
unnamed: U11.6, U13.4
unnamed: U11.8, U13.6
unnamed: U11.11, U13.8
unnamed: U12.3, U13.11
unnamed: U12.6, U13.13
unnamed: U12.8, U13.15
unnamed: U12.11, U13.17
unnamed: U15.2, U16.3
unnamed: U15.4, U16.6
unnamed: U15.6, U16.8
unnamed: U15.8, U16.11
unnamed: U15.11, U17.3
unnamed: U15.13, U17.6
unnamed: U15.15, U17.8
unnamed: U15.17, U17.11
OUTA0: H5.1, U8.2, U13.18
OUTA1: H5.2, U8.4, U13.16
OUTA2: H5.3, U8.6, U13.14
OUTA3: H5.4, U8.8, U13.12
OUTA4: H5.5, U8.17, U13.3
OUTA5: H5.6, U8.15, U13.5
OUTA6: H5.7, U8.13, U13.7
OUTA7: H5.8, U8.11, U13.9
OUTB0: H5.9, U9.2, U15.18
OUTB1: H5.10, U9.4, U15.16
OUTB2: H5.11, U9.6, U15.14
OUTB3: H5.12, U9.8, U15.12
OUTB4: H6.1, U9.17, U15.3
OUTB5: H6.2, U9.15, U15.5
OUTB6: H6.3, U9.13, U15.7
OUTB7: H6.4, U9.11, U15.9
OUTC0: H6.5, U10.2, U18.18
OUTC1: H6.6, U10.4, U18.16
OUTC2: H6.7, U10.6, U18.14
OUTC3: H6.8, U10.8, U18.12
OUTC4: H6.9, U10.17, U18.3
OUTC5: H6.10, U10.15, U18.5
OUTC6: H6.11, U10.13, U18.7
OUTC7: H6.12, U10.11, U18.9
READ0: H2.4, U3.1
READ1: H2.3, U3.2
READ2: H2.2, U3.3
READ3: H2.1, U1.3
READ4: H1.12, U3.5
READ5: H1.11, U3.4
RS02: U3.13, U8.1, U8.19
RS03: U3.12, U9.1, U9.19
RS04: U3.11, U10.1, U10.19
VCC: H1.1, U1.14, U2.16, U3.16, U4.20, U5.20, U6.20, U7.20, U8.20, U9.20, U10.20, U11.14, U12.14, U13.20, U14.16, U15.20, U16.14, U17.14, U18.20
WRITE0: H2.10, U2.1
WRITE1: H2.9, U2.2
WRITE2: H2.8, U2.3
WRITE3: H2.7, U1.1
WRITE4: H2.6, U2.5
WRITE5: H2.5, U2.4
WS01: U1.13, U2.14
WS02: U1.5, U2.13
WS03: U1.9, U2.12
WS04: U1.11, U2.11

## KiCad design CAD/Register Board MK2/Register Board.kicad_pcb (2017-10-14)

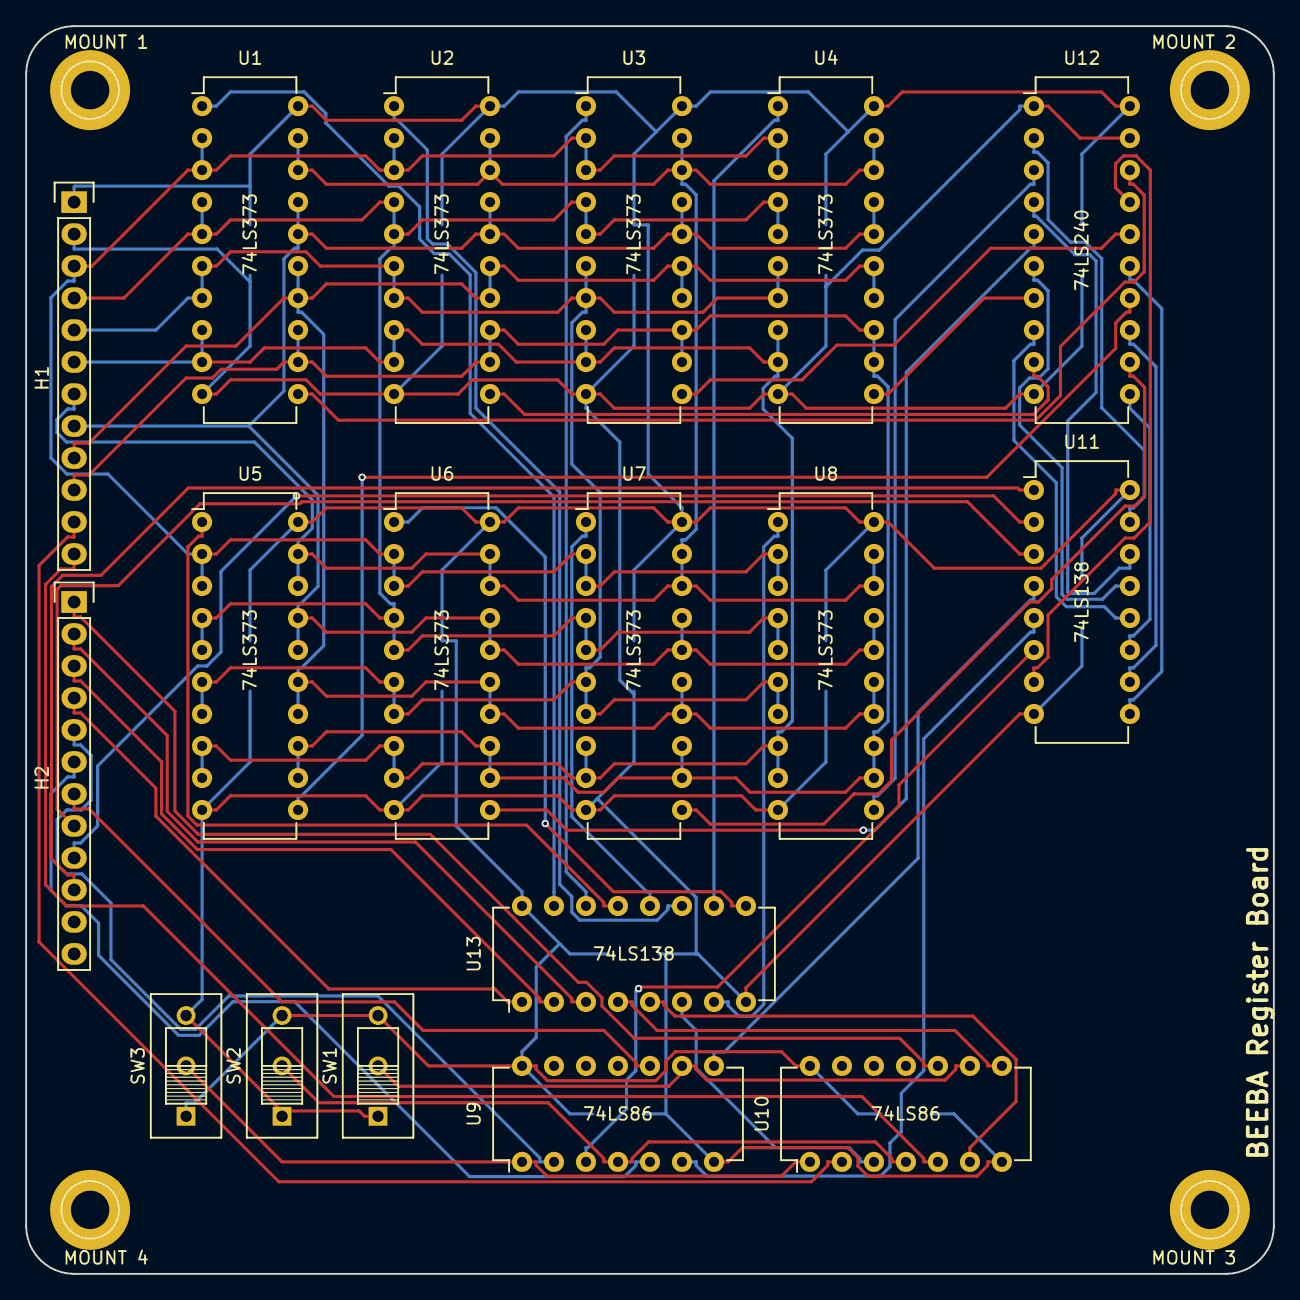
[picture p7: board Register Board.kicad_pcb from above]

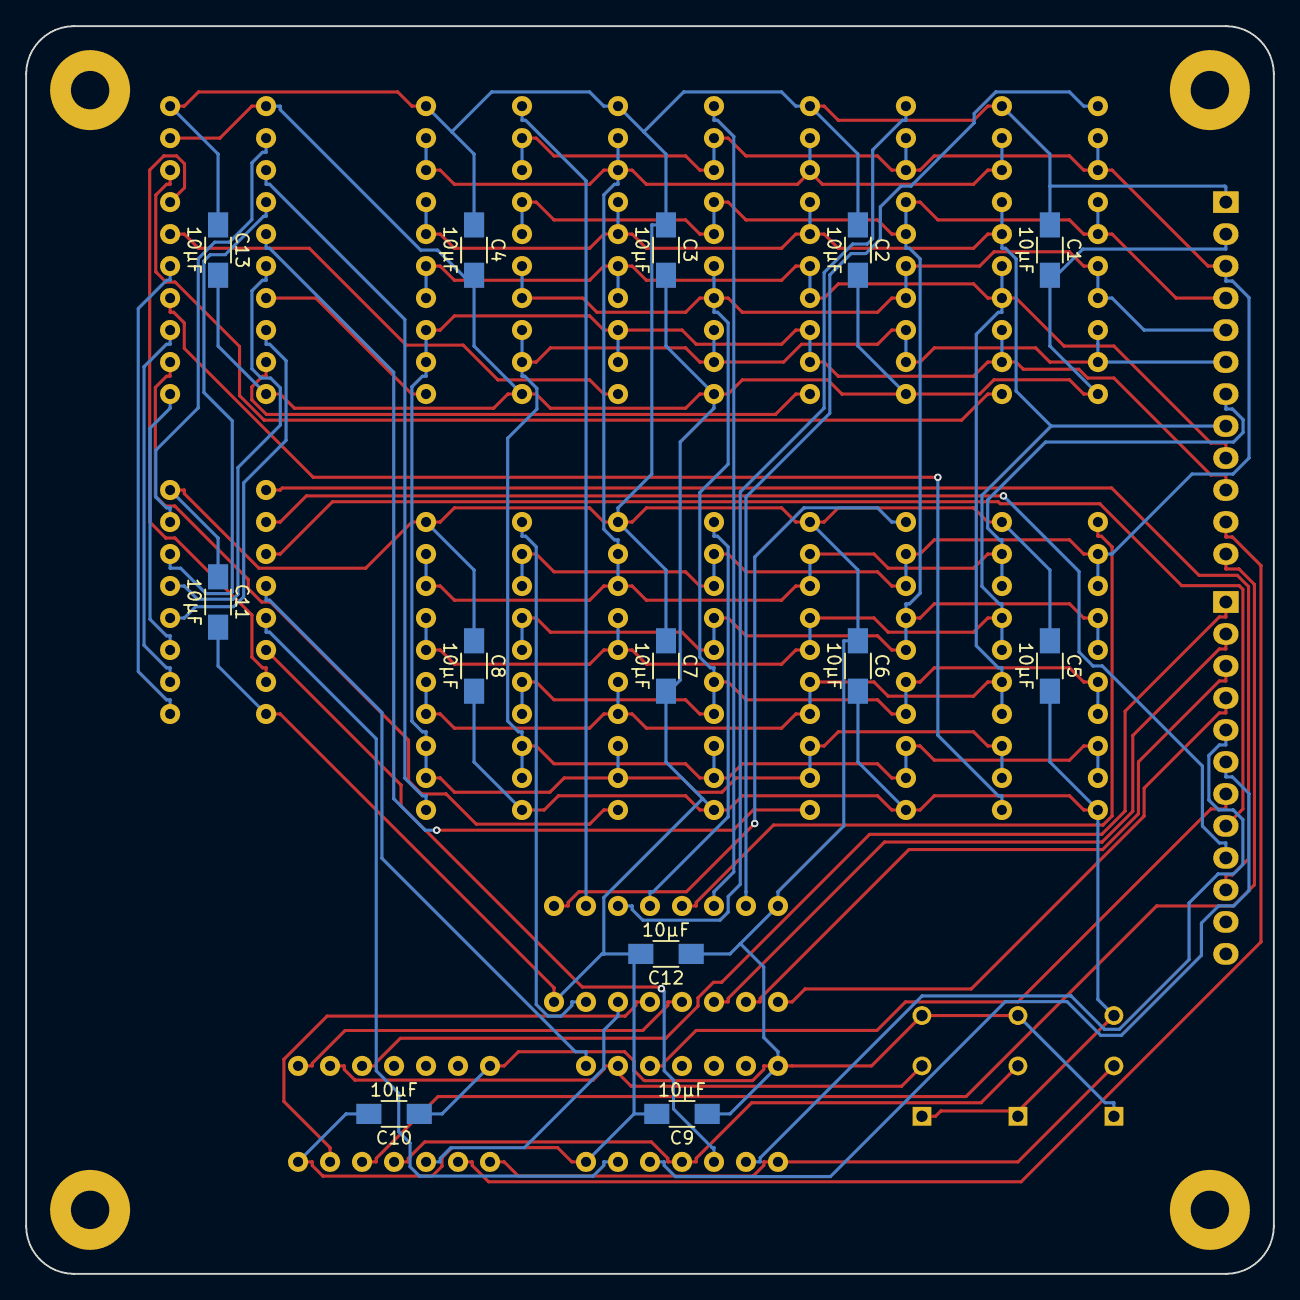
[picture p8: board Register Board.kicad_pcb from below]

Board: 2 copper layers, 99.1 x 99.1 mm, 35 parts (13 on the bottom side), 55 nets.

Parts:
C1, C2, C3, C4, C5, C6, C7, C8, C9, C10, C11, C12, C13: 10µF; C_1206_HandSoldering
H1, H2: CONN_01X12; Socket_Strip_Straight_1x12
MOUNT 1, MOUNT 2, MOUNT 3, MOUNT 4: 1pin
SW1, SW2, SW3: SWITCH_INV; SW_SPST_4mm_holes
U1, U2, U3, U4, U5, U6, U7, U8: 74LS373; DIP-20_W7.62mm
U9, U10: 74LS86; DIP-14_W7.62mm
U11, U13: 74LS138; DIP-16_W7.62mm
U12: 74LS240; DIP-20_W7.62mm

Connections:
DATA0: H1.10, U1.12, U1.13, U2.12, U2.13, U3.12, U3.13, U4.12, U4.13, U5.12, U5.13, U6.12, U6.13, U7.12, U7.13, U8.12, U8.13
DATA1: H1.9, U1.14, U1.15, U2.14, U2.15, U3.14, U3.15, U4.14, U4.15, U5.14, U5.15, U6.14, U6.15, U7.14, U7.15, U8.14, U8.15
DATA2: H1.8, U1.16, U1.17, U2.16, U2.17, U3.16, U3.17, U4.16, U4.17, U5.16, U5.17, U6.16, U6.17, U7.16, U7.17, U8.16, U8.17
DATA3: H1.7, U1.18, U1.19, U2.18, U2.19, U3.18, U3.19, U4.18, U4.19, U5.18, U5.19, U6.18, U6.19, U7.18, U7.19, U8.18, U8.19
DATA4: H1.6, U1.8, U1.9, U2.8, U2.9, U3.8, U3.9, U4.8, U4.9, U5.8, U5.9, U6.8, U6.9, U7.8, U7.9, U8.8, U8.9
DATA5: H1.5, U1.6, U1.7, U2.6, U2.7, U3.6, U3.7, U4.6, U4.7, U5.6, U5.7, U6.6, U6.7, U7.6, U7.7, U8.6, U8.7
DATA6: H1.4, U1.4, U1.5, U2.4, U2.5, U3.4, U3.5, U4.4, U4.5, U5.4, U5.5, U6.4, U6.5, U7.4, U7.5, U8.4, U8.5
DATA7: H1.3, U1.2, U1.3, U2.2, U2.3, U3.2, U3.3, U4.2, U4.3, U5.2, U5.3, U6.2, U6.3, U7.2, U7.3, U8.2, U8.3
GND: C1.2, C2.2, C3.2, C4.2, C5.2, C6.2, C7.2, C8.2, C9.2, C10.2, C11.2, C12.2, C13.2, H1.2, SW1.1, SW2.1, SW3.3, U1.10, U2.10, U3.10, U4.10, U5.10, U6.10, U7.10, U8.10, U9.7, U10.7, U11.8, U12.1, U12.10, U12.19, U13.8
unnamed: U10.3, U13.6
unnamed: U10.6, U13.5
unnamed: U10.8, U13.4
unnamed: U9.8, U11.4
unnamed: U9.6, U11.5
unnamed: U9.3, U11.6
unnamed: U11.7, U12.17
unnamed: U11.9, U12.15
unnamed: U11.10, U12.13
unnamed: U11.11, U12.11
unnamed: U11.12, U12.8
unnamed: U11.13, U12.6
unnamed: U11.14, U12.4
unnamed: U11.15, U12.2
RE0: U1.1, U13.15
RE1: U3.1, U13.14
RE2: U5.1, U13.13
RE3: U7.1, U13.12
RE4: U2.1, U13.11
RE5: U4.1, U13.10
RE6: U6.1, U13.9
RE7: U8.1, U13.7
READ0: H2.4, U13.1
READ1: H2.3, U13.2
READ2: H2.2, U13.3
READ3: H2.1, U10.10
READ4: H1.12, U10.5
READ5: H1.11, U10.2
SEL1: SW1.2, U9.9, U10.9
SEL2: SW2.2, U9.4, U10.4
SEL3: SW3.2, U9.1, U10.1
VCC: C1.1, C2.1, C3.1, C4.1, C5.1, C6.1, C7.1, C8.1, C9.1, C10.1, C11.1, C12.1, C13.1, H1.1, SW1.3, SW2.3, SW3.1, U1.20, U2.20, U3.20, U4.20, U5.20, U6.20, U7.20, U8.20, U9.14, U10.14, U11.16, U12.20, U13.16
WE0: U1.11, U12.18
WE1: U3.11, U12.16
WE2: U5.11, U12.14
WE3: U7.11, U12.12
WE4: U2.11, U12.9
WE5: U4.11, U12.7
WE6: U6.11, U12.5
WE7: U8.11, U12.3
WRITE0: H2.10, U11.1
WRITE1: H2.9, U11.2
WRITE2: H2.8, U11.3
WRITE3: H2.7, U9.10
WRITE4: H2.6, U9.5
WRITE5: H2.5, U9.2

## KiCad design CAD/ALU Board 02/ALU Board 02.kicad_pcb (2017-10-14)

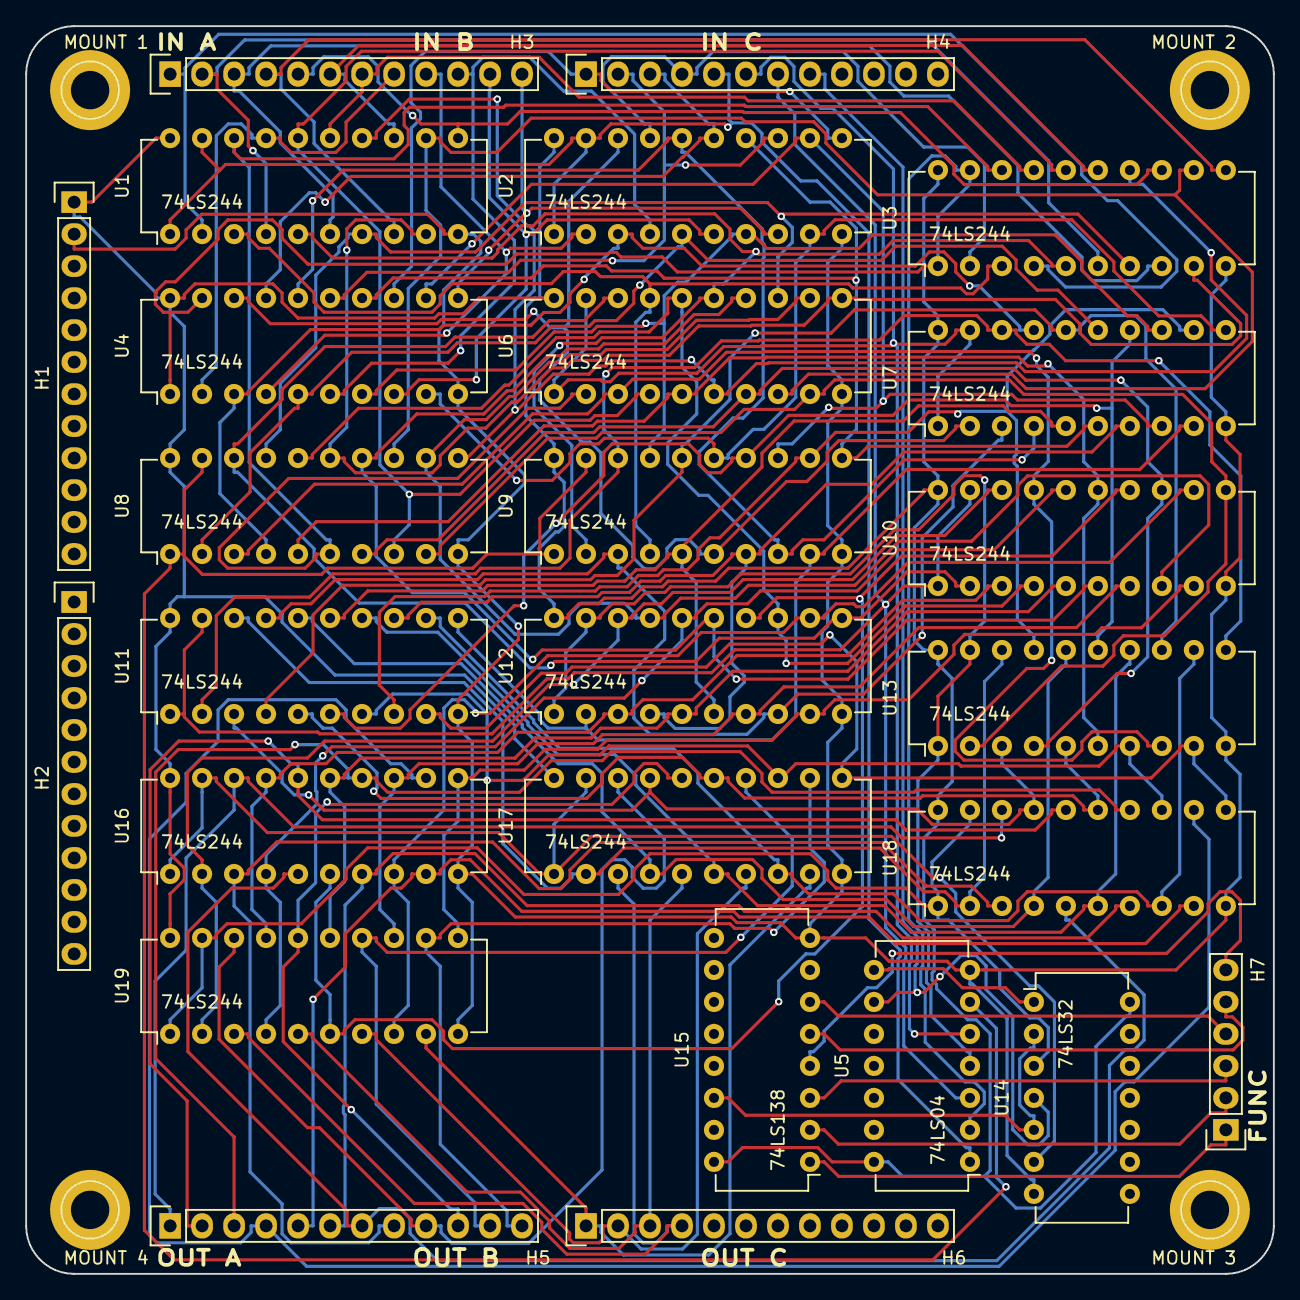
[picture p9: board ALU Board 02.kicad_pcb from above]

Board: 2 copper layers, 99.1 x 99.1 mm, 30 parts (0 on the bottom side), 99 nets.

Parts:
H1, H2, H3, H4, H5, H6: CONN_01X12; Socket_Strip_Straight_1x12
H7: CONN_01X06; Socket_Strip_Straight_1x06
MOUNT 1, MOUNT 2, MOUNT 3, MOUNT 4: 1pin
U1, U2, U3, U4, U6, U7, U8, U9, U10, U11, U12, U13, U16, U17, U18, U19: 74LS244; DIP-20_W7.62mm
U5: 74LS04; DIP-14_W7.62mm
U14: 74LS32; DIP-14_W7.62mm
U15: 74LS138; DIP-16_W7.62mm

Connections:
FS09: U14.2, U14.5, U15.14
FUNC0: H7.1, U15.1
FUNC1: H7.2, U15.2
FUNC2: H7.3, U15.3
FUNC3: H7.4, U15.6
FUNC4: H7.5, U15.5
FUNC5: H7.6, U15.4
GND: H1.2, U1.10, U2.10, U3.10, U4.10, U5.7, U6.10, U7.10, U8.10, U9.10, U10.10, U11.10, U12.10, U13.10, U14.7, U15.8, U16.10, U17.10, U18.10, U19.10
INA0: H3.1, U1.2, U3.4
INA1: H3.2, U1.4, U3.6
INA2: H3.3, U1.6, U3.8
INA3: H3.4, U1.8, U3.11
INA4: H3.5, U1.11, U3.13
INA5: H3.6, U1.13, U3.15
INA6: H3.7, U1.15, U3.17
INA7: H3.8, U1.17, U4.2
INB0: H3.9, U2.2, U4.4
INB1: H3.10, U2.4, U4.6
INB2: H3.11, U2.6, U4.8
INB3: H3.12, U2.8, U4.11
INB4: H4.1, U2.11, U4.13
INB5: H4.2, U2.13, U4.15
INB6: H4.3, U2.15, U4.17
INB7: H4.4, U2.17, U3.2
INC0: H4.5, U1.1, U1.19, U2.1, U2.19, U5.1
INC1: H4.6, U5.5, U6.1, U6.19, U7.1, U7.19
INC2: H4.7, U5.3, U10.1, U10.19, U11.1, U11.19
INC3: H4.8, U5.9, U14.4
NINC0: U3.1, U3.19, U4.1, U4.19, U5.2
NINC1: U5.6, U8.1, U8.19, U9.1, U9.19
NINC2: U5.4, U12.1, U12.19, U13.1, U13.19
NINC3: U14.3, U18.1, U18.19, U19.1, U19.19
unnamed: U5.8, U14.1
OUTA0: H5.1, U16.18, U18.18
OUTA1: H5.2, U16.16, U18.16
OUTA2: H5.3, U16.14, U18.14
OUTA3: H5.4, U16.12, U18.12
OUTA4: H5.5, U16.9, U18.9
OUTA5: H5.6, U16.7, U18.7
OUTA6: H5.7, U16.5, U18.5
OUTA7: H5.8, U16.3, U18.3
OUTB0: H5.9, U17.18, U19.18
OUTB1: H5.10, U17.16, U19.16
OUTB2: H5.11, U17.14, U19.14
OUTB3: H5.12, U17.12, U19.12
OUTB4: H6.1, U17.9, U19.9
OUTB5: H6.2, U17.7, U19.7
OUTB6: H6.3, U17.5, U19.5
OUTB7: H6.4, U17.3, U19.3
SHA00: U1.18, U3.18, U6.2, U8.6
SHA01: U1.16, U3.16, U6.4, U8.8
SHA02: U1.14, U3.14, U6.6, U8.11
SHA03: U1.12, U3.12, U6.8, U8.13
SHA04: U1.9, U3.9, U6.11, U8.15
SHA05: U1.7, U3.7, U6.13, U8.17
SHA06: U1.5, U3.5, U6.15, U9.2
SHA07: U1.3, U3.3, U6.17, U9.4
SHA08: U2.18, U4.18, U7.2, U9.6
SHA09: U2.16, U4.16, U7.4, U9.8
SHA10: U2.14, U4.14, U7.6, U9.11
SHA11: U2.12, U4.12, U7.8, U9.13
SHA12: U2.9, U4.9, U7.11, U9.15
SHA13: U2.7, U4.7, U7.13, U9.17
SHA14: U2.5, U4.5, U7.15, U8.2
SHA15: U2.3, U4.3, U7.17, U8.4
SHB00: U6.18, U8.18, U10.2, U12.11
SHB01: U6.16, U8.16, U10.4, U12.13
SHB02: U6.14, U8.14, U10.6, U12.15
SHB03: U6.12, U8.12, U10.8, U12.17
SHB04: U6.9, U8.9, U10.11, U13.2
SHB05: U6.7, U8.7, U10.13, U13.4
SHB06: U6.5, U8.5, U10.15, U13.6
SHB07: U6.3, U8.3, U10.17, U13.8
SHB08: U7.18, U9.18, U11.2, U13.11
SHB09: U7.16, U9.16, U11.4, U13.13
SHB10: U7.14, U9.14, U11.6, U13.15
SHB11: U7.12, U9.12, U11.8, U13.17
SHB12: U7.9, U9.9, U11.11, U12.2
SHB13: U7.7, U9.7, U11.13, U12.4
SHB14: U7.5, U9.5, U11.15, U12.6
SHB15: U7.3, U9.3, U11.17, U12.8
SHC00: U10.18, U12.18, U16.2, U19.2
SHC01: U10.16, U12.16, U16.4, U19.4
SHC02: U10.14, U12.14, U16.6, U19.6
SHC03: U10.12, U12.12, U16.8, U19.8
SHC04: U10.9, U12.9, U16.11, U19.11
SHC05: U10.7, U12.7, U16.13, U19.13
SHC06: U10.5, U12.5, U16.15, U19.15
SHC07: U10.3, U12.3, U16.17, U19.17
SHC08: U11.18, U13.18, U17.2, U18.2
SHC09: U11.16, U13.16, U17.4, U18.4
SHC10: U11.14, U13.14, U17.6, U18.6
SHC11: U11.12, U13.12, U17.8, U18.8
SHC12: U11.9, U13.9, U17.11, U18.11
SHC13: U11.7, U13.7, U17.13, U18.13
SHC14: U11.5, U13.5, U17.15, U18.15
SHC15: U11.3, U13.3, U17.17, U18.17
VCC: H1.1, U1.20, U2.20, U3.20, U4.20, U5.14, U6.20, U7.20, U8.20, U9.20, U10.20, U11.20, U12.20, U13.20, U14.14, U15.16, U16.20, U17.20, U18.20, U19.20
YINC3: U14.6, U16.1, U16.19, U17.1, U17.19

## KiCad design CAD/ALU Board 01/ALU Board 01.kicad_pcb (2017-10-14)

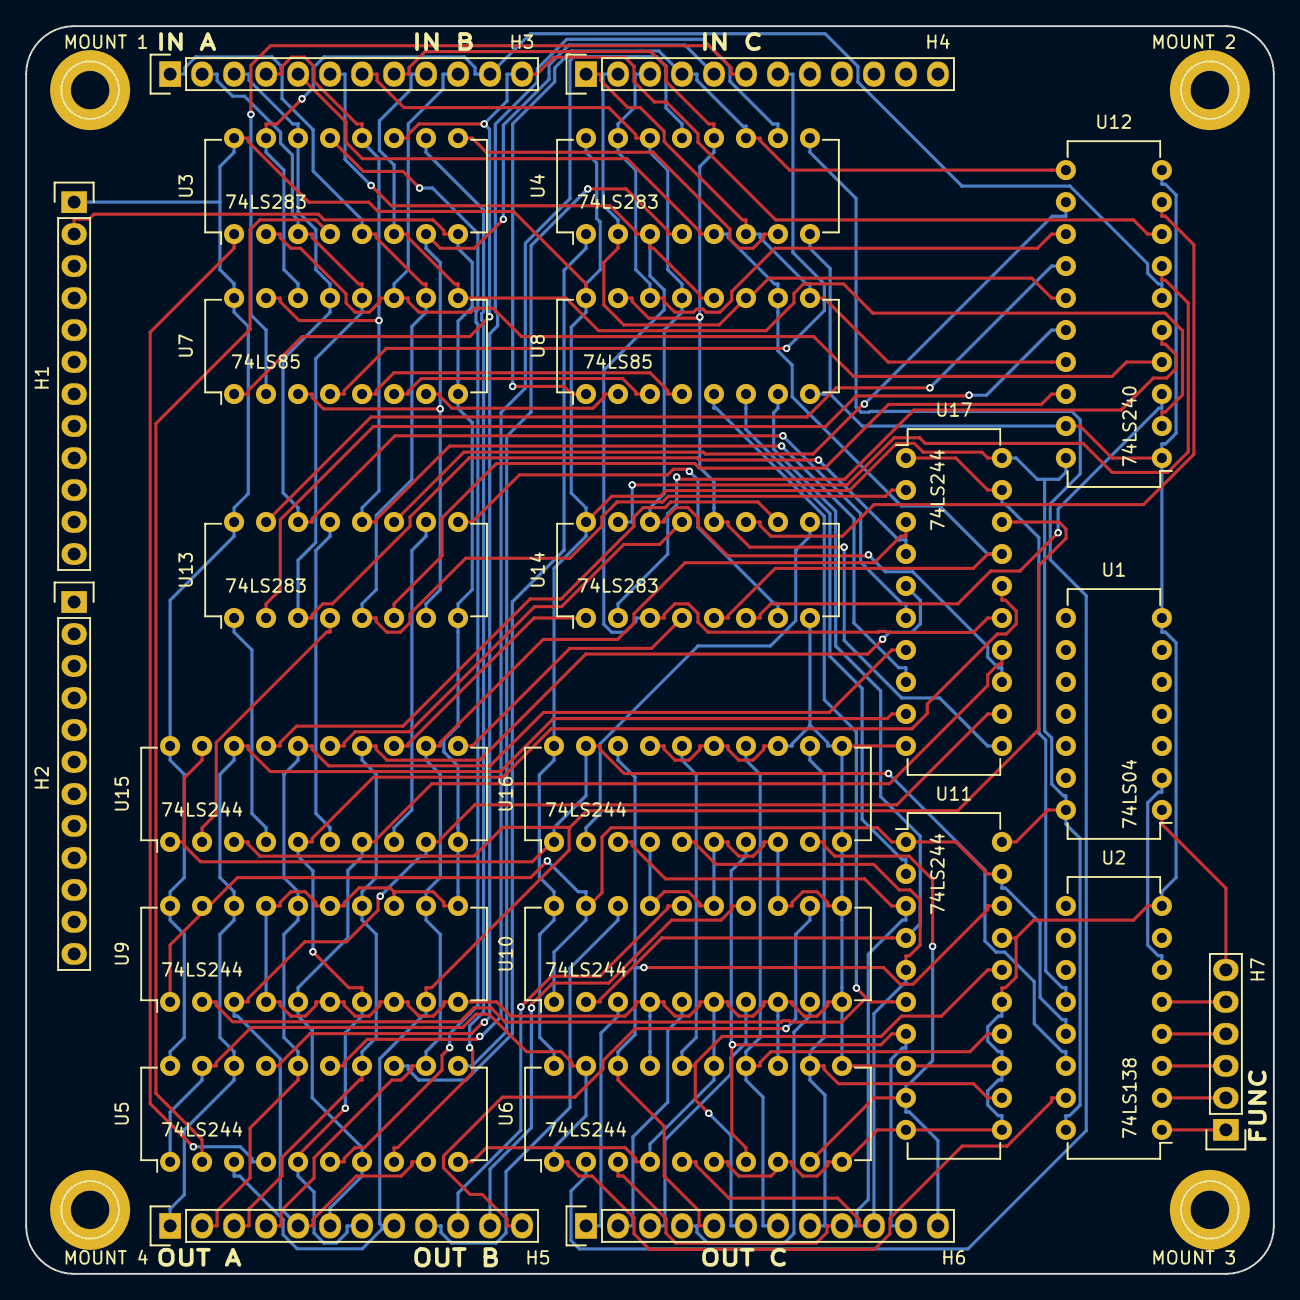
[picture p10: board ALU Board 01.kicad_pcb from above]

Board: 2 copper layers, 99.1 x 99.1 mm, 28 parts (0 on the bottom side), 90 nets.

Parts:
H1, H2, H3, H4, H5, H6: CONN_01X12; Socket_Strip_Straight_1x12
H7: CONN_01X06; Socket_Strip_Straight_1x06
MOUNT 1, MOUNT 2, MOUNT 3, MOUNT 4: 1pin
U1: 74LS04; DIP-14_W7.62mm
U2: 74LS138; DIP-16_W7.62mm
U3, U4, U13, U14: 74LS283; DIP-16_W7.62mm
U5, U6, U9, U10, U11, U15, U16, U17: 74LS244; DIP-20_W7.62mm
U7, U8: 74LS85; DIP-16_W7.62mm
U12: 74LS240; DIP-20_W7.62mm

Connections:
FS00: U2.15, U5.1, U5.19, U6.1, U6.19
FS01: U2.14, U15.1, U15.19, U16.1, U16.19
FS02: U2.13, U9.1, U9.19, U10.1, U10.19, U11.1, U11.19
FS03: U2.12, U17.1, U17.19
FUNC0: H7.1, U2.1
FUNC1: H7.2, U2.2
FUNC2: H7.3, U2.3
FUNC3: H7.4, U2.4
FUNC4: H7.5, U2.5
FUNC5: H7.6, U1.1
GND: H1.2, U1.7, U2.8, U3.8, U4.8, U5.10, U6.4, U6.6, U6.8, U6.10, U6.11, U6.13, U6.15, U6.17, U7.8, U8.8, U9.4, U9.6, U9.8, U9.10, U9.11, U9.13, U9.15, U9.17, U10.4, U10.6, U10.8, U10.10, U10.11, U10.13, U10.15, U10.17, U11.8, U11.10, U11.11, U11.13, U11.15, U11.17, U12.1, U12.10, U12.19, U13.8, U14.8, U15.10, U16.4, U16.6, U16.8, U16.10, U16.11, U16.13, U16.15, U16.17, U17.10
INA0: H3.1, U3.5, U7.10, U13.5, U17.2
INA1: H3.2, U3.3, U7.12, U13.3, U17.4
INA2: H3.3, U3.14, U7.13, U13.14, U17.6
INA3: H3.4, U3.12, U7.15, U13.12, U17.8
INA4: H3.5, U4.5, U8.10, U14.5, U17.17
INA5: H3.6, U4.3, U8.12, U14.3, U17.15
INA6: H3.7, U4.14, U8.13, U14.14, U17.13
INA7: H3.8, U4.12, U8.15, U14.12, U17.11
INB0: H3.9, U3.6, U7.9, U12.2
INB1: H3.10, U3.2, U7.11, U12.4
INB2: H3.11, U3.15, U7.14, U12.6
INB3: H3.12, U3.11, U7.1, U12.8
INB4: H4.1, U4.6, U8.9, U12.17
INB5: H4.2, U4.2, U8.11, U12.15
INB6: H4.3, U4.15, U8.14, U12.13
INB7: H4.4, U4.11, U8.1, U12.11
INC0: H4.5, U3.7, U7.3, U13.7
INC1: H4.6, U7.2
INC2: H4.7, U7.4
NINB0: U12.18, U13.6
NINB1: U12.16, U13.2
NINB2: U12.14, U13.15
NINB3: U12.12, U13.11
NINB4: U12.3, U14.6
NINB5: U12.5, U14.2
NINB6: U12.7, U14.15
NINB7: U12.9, U14.11
unnamed: U1.2, U2.6
unnamed: U3.1, U5.4
unnamed: U3.4, U5.2
unnamed: U3.9, U4.7
unnamed: U3.10, U5.8
unnamed: U3.13, U5.6
unnamed: U4.1, U5.13
unnamed: U4.4, U5.11
unnamed: U4.9, U6.2
unnamed: U4.10, U5.17
unnamed: U4.13, U5.15
unnamed: U7.5, U8.4
unnamed: U7.6, U8.3
unnamed: U7.7, U8.2
unnamed: U8.7, U10.2, U11.4
unnamed: U8.6, U11.2
unnamed: U8.5, U9.2, U11.6
unnamed: U13.1, U15.4
unnamed: U13.4, U15.2
unnamed: U13.9, U14.7
unnamed: U13.10, U15.8
unnamed: U13.13, U15.6
unnamed: U14.1, U15.13
unnamed: U14.4, U15.11
unnamed: U14.9, U16.2
unnamed: U14.10, U15.17
unnamed: U14.13, U15.15
OUTA0: H5.1, U5.18, U9.18, U15.18, U17.9
OUTA1: H5.2, U5.16, U9.16, U15.16, U17.7
OUTA2: H5.3, U5.14, U9.14, U15.14, U17.5
OUTA3: H5.4, U5.12, U9.12, U15.12, U17.3
OUTA4: H5.5, U5.9, U9.3, U15.9, U17.12
OUTA5: H5.6, U5.7, U9.5, U15.7, U17.14
OUTA6: H5.7, U5.5, U9.7, U15.5, U17.16
OUTA7: H5.8, U5.3, U9.9, U15.3, U17.18
OUTB0: H5.9, U10.18
OUTB1: H5.10, U10.16
OUTB2: H5.11, U10.14
OUTB3: H5.12, U10.12
OUTB4: H6.1, U10.3
OUTB5: H6.2, U10.5
OUTB6: H6.3, U10.7
OUTB7: H6.4, U10.9
OUTC0: H6.5, U6.18, U11.18, U16.18
OUTC1: H6.6, U6.16, U11.16, U16.16
OUTC2: H6.7, U6.14, U11.14, U16.14
OUTC3: H6.8, U6.12, U11.12, U16.12
OUTC4: H6.9, U6.3, U11.3, U16.3
OUTC5: H6.10, U6.5, U11.5, U16.5
OUTC6: H6.11, U6.7, U11.7, U16.7
OUTC7: H6.12, U6.9, U11.9, U16.9
VCC: H1.1, U1.14, U2.16, U3.16, U4.16, U5.20, U6.20, U7.16, U8.16, U9.20, U10.20, U11.20, U12.20, U13.16, U14.16, U15.20, U16.20, U17.20

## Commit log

2017-10-14 add design files, .gitignore
    Added files to the empty repository.
    [100x100mm Computer Board Template.kicad_pcb, 100x100mm Computer Board Template.sch, 100x100mm Computer Perf Board.kicad_pcb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]
2017-10-14 move CAD files, add assembler, write README
    Moved CAD files to the "CAD" folder. Added the assembler to the project. Wrote some documentation in README.md.
    [100x100mm Computer Board Template.kicad_pcb, 100x100mm Computer Board Template.sch, 100x100mm Computer Perf Board.kicad_pcb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]
2017-10-14 fix README.md
    Replaced greater than / less than characters with square brackets to avoid those characters being interpreted as HTML tags.
